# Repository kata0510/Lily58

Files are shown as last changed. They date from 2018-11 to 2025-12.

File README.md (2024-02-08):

# Lily58
Lily58 is 6*4+4keys column-staggered split keyboard.
Lily58Lite-Pic

## [Document Site Here](https://kata0510.github.io/Lily58-Document/)

# Type

- Lily58 Pro
  - [PCB Data](https://github.com/kata0510/Lily58/tree/master/Pro/PCB)
  - [BuildGuide JP](https://kata0510.github.io/Lily58-Document/Lily58_Pro_BG/)
  - [BuildGuide EN](https://github.com/kata0510/Lily58/blob/master/Pro/Doc/buildguide_en.md)
  - [BuildGuide IT](https://github.com/kata0510/Lily58/blob/master/Pro/Doc/buildguide_it.md)
  - [Shop(Yushakobo)](https://yushakobo.jp/shop/lily58-pro/)
- Lily58 Lite Rev2
  - [BuildGuide(YouTube)](https://www.youtube.com/watch?v=t6HLQvqlsVM)
  - [BuildInfo](https://kata0510.github.io/Lily58-Document/Lily58_Lite_Rev2_help.md)
  - [Shop(BOOTH)](https://booth.pm/ja/items/1963895)
  - [Shop(Yushakobo)](https://yushakobo.jp/shop/consign_lily58-lite-rev2/)
- Lily58(Old)
  - [PCB Data](https://github.com/kata0510/Lily58/tree/master/pcb)
  - [BuildGuide](https://kata0510.github.io/Lily58-Document/Lily58_BG/)
- Lily58 Lite Rev1(Old)
  - [PCB Data](https://github.com/kata0510/Lily58/tree/master/pcb)
  - [BuildGuide](https://kata0510.github.io/Lily58-Document/Lily58_Lite_BG/)

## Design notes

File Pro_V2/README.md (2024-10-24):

# Lily58 Pro v2
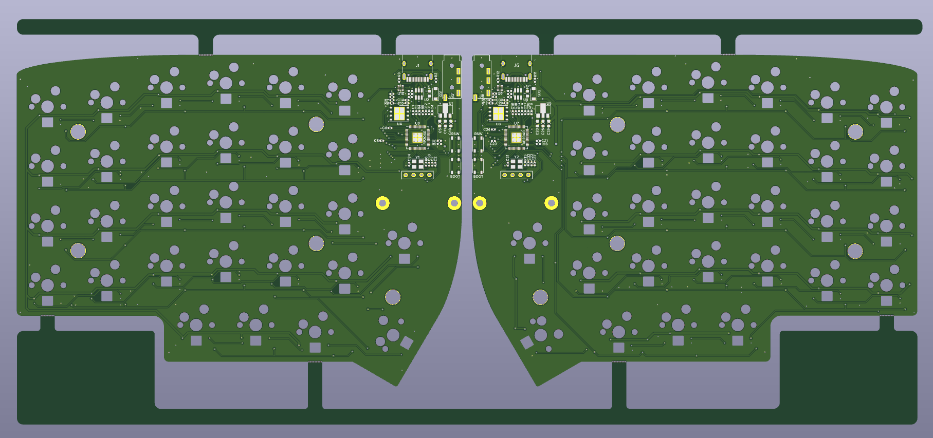
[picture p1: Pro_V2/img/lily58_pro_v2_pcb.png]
Lily58 Pro v2 PCB


### description
- MCU: [RP2040](https://www.raspberrypi.com/documentation/microcontrollers/rp2040.html)
- PCBA Design
- Backlight Support
- Firmware: QMK Firmware

### Assembly Guide
- TBA

### BOM
http://lily58-public.s3-website-ap-northeast-1.amazonaws.com/Lily58_Pro_V2_BOM.html

### Shop
- TBA

### Features
- Choc V2 Switch Support

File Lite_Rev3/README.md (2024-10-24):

# Lily58 Lite Rev3
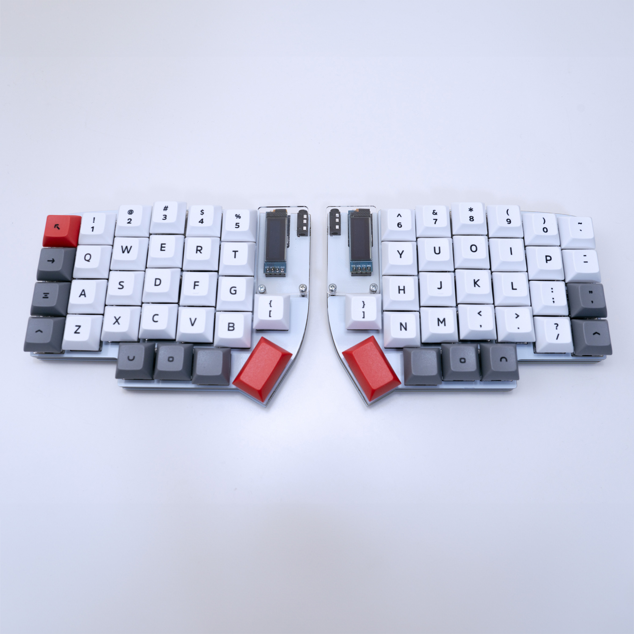
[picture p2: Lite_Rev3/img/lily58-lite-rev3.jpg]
Lily58 Lite Rev3

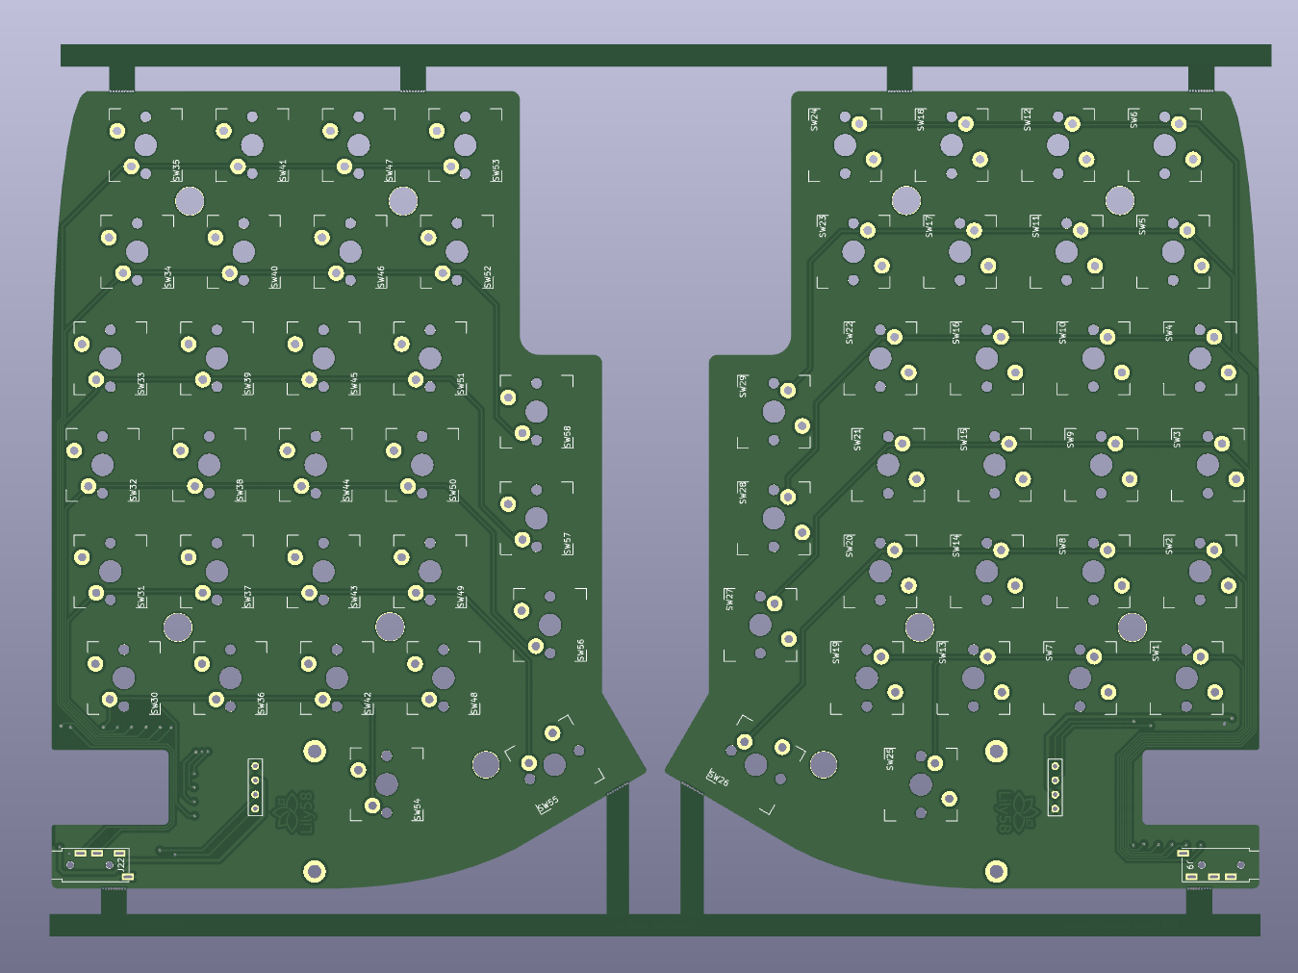
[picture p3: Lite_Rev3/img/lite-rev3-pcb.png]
Lily58 Lite Rev3 PCB

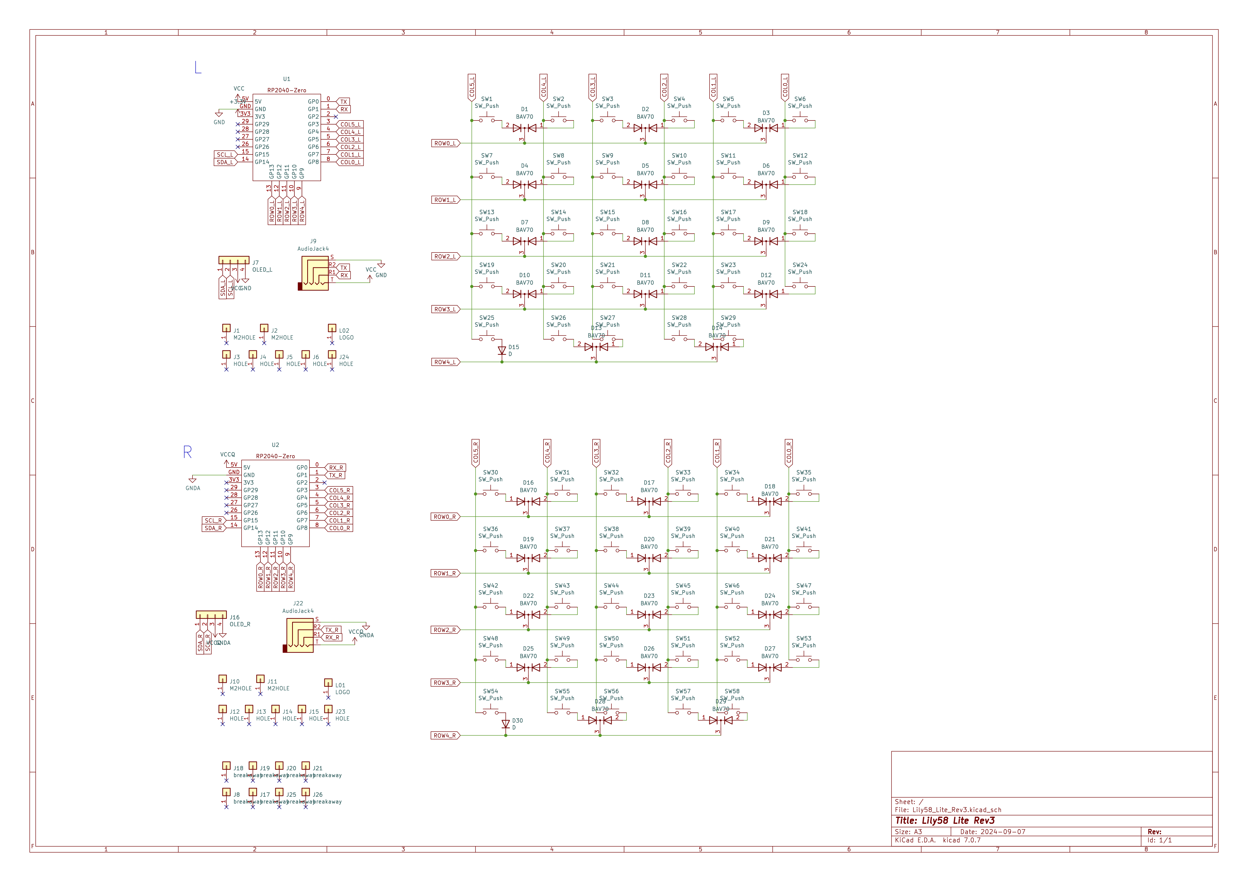
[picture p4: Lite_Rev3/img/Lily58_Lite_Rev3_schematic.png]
Lily58 Lite Rev3 Schematic


### description
- Controller: RP2040-Zero
- Firmware: QMK Firmware

### Assembly Guide
- https://docs.liliums.net/lily58-lite-rev3/about/ (RP2040 installed kit Version)

### Shop
- https://shop.liliums.net/products/lily58-lite-rev3
- https://shop.yushakobo.jp/products/9651

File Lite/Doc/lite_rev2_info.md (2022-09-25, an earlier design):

## 新しいビルドガイドページを参照ください
[https://kata0510.github.io/Lily58-Document/Lily58_Lite_Rev2/](https://kata0510.github.io/Lily58-Document/Lily58_Lite_Rev2/)

## キット組み立てに関する詳細は以下のYouTube動画を参照下さい  
(https://www.youtube.com/watch?v=t6HLQvqlsVM)  

## 組み立てに必要な工具/部品一覧
## 必要な道具
||道具名|備考|
|:---:|---|---|
|1|はんだごて|FX-600等の温調機能があるタイプを推奨|
|2|はんだ||
|3|精密プラスドライバー||
|4|マスキングテープ|はんだ付けする前にパーツを固定するために必要です|
  
## 必要な部品
||パーツ|数量|購入先|
|:---:|---|---|---|
|1|Pro Micro(コンスルー付き)|2|[遊舎工房](https://yushakobo.jp/shop/promicro-spring-pinheader/)|
|2|キースイッチ(MX互換スイッチ※1)|58|[遊舎工房](https://yushakobo.jp/product-category/switches/)など|
|3|キーキャップ|58|[遊舎工房](https://yushakobo.jp/product-category/keycaps/),[TALP KEYBOARD](https://talpkeyboard.stores.jp/)など|
|4|MicroUSB|1|データ通信に対応している物を使用してください|
|5|TRRSケーブル|1|[遊舎工房](https://yushakobo.jp/shop/trrs_cable/)など|
|6|OLEDモジュール(オプション)※2|2|[遊舎工房](https://yushakobo.jp/shop/oled/)|

迷ったときのおすすめ  
キースイッチ:Gateron Silent Red  
https://yushakobo.jp/shop/a02gs/  
  
キーキャップ:MDA BigBang 
https://yushakobo.jp/shop/mda-big-bang-2-0/

※1 CherryMX互換スイッチのみの対応です。ロープロファイルスイッチは使用できません。  
  
※2 OLEDを使用しない場合は以下の手順を行ってください。
  
## OLEDを取り付けない場合
OLEDを取り付けない場合はファームウェアのOLED機能をOFFにする必要があります。  
以下のOLED機能をオフにしたファームウェアをダウンロードしていただき、QMKToolboxで書き込んでいただく、   
もしくはご自身で環境を作っていただきファームウェアをコンパイルして頂く必要がございます。  
‘qmk_firmware/keyboards/lily58/rules.mk‘と  
‘qmk_firmware/keyboards/lily58/keymaps/[キーマップ]/rules.mk‘の‘OLED_DRIVER_ENABLE = yes‘をnoにしてコンパイルし、書き込んでください。

OLEDオフにしたデフォルトキーマップhexファイル
[ダウンロード(lily58_rev1_default.hex)](https://drive.google.com/uc?export=download&id=1yPxZlVRVBfqq0-pEKkJZc93vqW6Jdboj)

## 困ったときは
### 同梱品の部品が足りない
A. 以下のお問合せ先よりご連絡ください。不足分をお送りさせていただきます。  
Twitter:@F_YUUCHI mail:yuchi.kbd@gmail.com 

### Q.1列(複数列)又は1行(複数行)キースイッチが反応しない
A.ProMicroのはんだ付け、取り付けしっかりとできてない場合があります。  
再度確認し、必要に応じて再度はんだ付け、取り付けを行ってください。  

### Q.キースイッチが単体で反応しない
A.キースイッチのはんだづけのはんだ付けに問題がある可能性があります。  
はんだ付けでも解決しない場合、キースイッチが故障している可能性があるため交換が必要です。  

### キーの入力が1つ目で止まる、連続でキーの入力ができない
OLEDを取り付けてない場合ファームウェアでオフにする必要があります。
上記の「OLEDを取り付けてない場合」の手順を行ってください。

**解決しない場合はお気軽にDiscordサーバー([Self-Made Keyboards in Japan](https://discordapp.com/invite/NM7XtDW))の「#clinic-readme」チャンネルを見ていただき相談いただくか、Twitter:@F_YUUCHIにメッセージをお送りください**

## カスタマイズ情報
### Type-C化する
Elite-C LPを購入しProMicroと交換することで接続コネクタをType-C化することができます。  
動作保証いたしかねます。購入される際は事前に調べてからご購入ください。  
https://yushakobo.jp/shop/elite-c-lp/  

### Bluetooth化する
BLE Micro Proを購入しProMicroと交換することでBluetooth化することができます。  
動作保証いたしかねます。導入難易度が高いため購入される際は事前に調べてからご購入ください。  
[https://yushakobo.jp/shop/ble-micro-pro/](https://yushakobo.jp/shop/ble-micro-pro/)

### ケーブルを自作する
MicroUSBケーブルやTRRSケーブルを自作するキットでオリジナルのケーブルを自作することができます  
[https://yushakobo.jp/shop/self-made-cable/](https://yushakobo.jp/shop/self-made-cable/)

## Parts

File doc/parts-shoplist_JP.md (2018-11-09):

| パーツ名 | 販売店舗 |　備考  |
|---|---|---|
|Lily56 ケース|[遊舎工房レーザーカットサービス](https://yushakobo.jp/lasercut/)|Lily58/case/yushakobo-A4.aiデータをA4サイズで発注|
|ProMicro|[遊舎工房](https://yushakobo.jp/shop/promicro-spring-pinheader/)<br> [TALP KEYBOARD](https://talpkeyboard.stores.jp/items/5b24504ba6e6ee7ec60063e3)||
|キースイッチ|[遊舎工房](https://yushakobo.jp/product-category/switches/)<br>[TALP KEYBOARD](https://talpkeyboard.stores.jp/?category_id=59cf8860ed05e668db003f5d)||
|キーキャップ|[遊舎工房](https://yushakobo.jp/product-category/switches/)<br>[TALP KEYBOARD](https://talpkeyboard.stores.jp/?category_id=59be183f428f2d49120007b1)|CherryMX系はTALP KEYBOARD、Kailhロープロ系は遊舎工房での取り扱い|
|ダイオード 1N4148|[秋月電子](http://akizukidenshi.com/catalog/g/gI-00941/)<br>[TALP KEYBOARD](https://talpkeyboard.stores.jp/items/59eadbffc8f22c15de001638)||
|タクトスイッチ|[秋月電子](http://akizukidenshi.com/catalog/g/gP-08074/)|すべて白色のスイッチは国内取扱いなし|
|TRRSジャック|[秋月電子](http://akizukidenshi.com/catalog/g/gC-06070/)||
|M2 スペーサー 6mm,10mm|[ヒロスギネット(6mm)](http://www.hirosugi-net.co.jp/shop/g/g63/)<br>[ヒロスギネット(10mm)](http://www.hirosugi-net.co.jp/shop/g/g71/)||

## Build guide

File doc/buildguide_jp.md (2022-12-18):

# Lily58 ビルドガイド 

## 新しいビルドガイドページを参照ください
[https://kata0510.github.io/Lily58-Document/Lily58_BG/](https://kata0510.github.io/Lily58-Document/Lily58_BG/)

## 必要部品

| パーツ名 |  個数  |  備考  |
|---|---|---|
|Lily58 PCB | 2枚 ||
|Lily58 ケース|1セット||
|ProMicro|2個|はんだ付けの回数が減り、破損しやすいコネクタのため交換が可能になるため別売の[コンスルー](https://yushakobo.jp/shop/a01mc-00/)の使用を推奨|
|キースイッチ(CherryMX,PG1350)|58pcs ※|ALPS軸非対応|
|キーキャップ|1U 56個 1.5U 2個※|1.5Uの部分は1Uでも可|
|ダイオード 1N4148|58本(個)||
|タクトスイッチ|2個||
|TRRSジャック|2個||
|M2 スペーサー 6mm,10mm|10個,4個||
|M2 ネジ 5mm|28個||
|TRS(TRRS)ケーブル|1本|AUXケーブルと言われるオーディオ用のケーブルです|
|MicroUSBケーブル|1本|Pro Micro側のコネクタの耐久性が低いためマグネット式を推奨|

※キットには付属していないため用意が必要です。

## ダイオードを取り付ける
**ロープロファイルスイッチを使用する場合スイッチを取り付けるアクリルプレートとPCBの間の高さを稼げないため別売の[表面実装ダイオード(1N4148W)](http://akizukidenshi.com/catalog/g/gI-07084/)を使用することを推奨します。
付属の足付きダイオードを使用する場合ははんだ付けした面の飛び出しを最小限にする必要があります。(足をカットしてからはんだ付けを行う)**

このPCBはリバーシブルなので**片面づつに**部品を実装していきます。ダイオードを実装する面(オレンジの部品が見える方)が裏面の扱いになります。

横から見るとこのような図になります
PCB2

ダイオードの足を曲げます。
ケース3枚を重ねた状態のものに押し当てると簡単にダイオードの足を曲げることができます。  

 
 PCBの裏側(スイッチやProMicroを取り付けるのと反対側)に折り曲げたダイオードを差し込みます。  
ダイオードには向きがあります。PCBの表記を確認して正しい方向に差し込んで下さい。  
以下の画像のようにダイオードの黒い線が常に基板の表示の三角形の横棒のある方向に向いた状態ではんだ付けをしてください。向きが正しくないとキーが反応しません。
46900579-542c0500-cedf-11e8-87a7-07f710f7e78e
diode  
  
裏側からはんだ付けを行いますが落ちてしまうため、マスキングテープなどで止めます。止める際にダイオードが浮かないようにテープの上から力を加えて抑えながら仮固定します。

はんだ付けを行います。
unadjustednonraw_thumb_2d42

はんだ付けが終わったらダイオードの足をニッパー等でカットします。カットするときに足が飛びやすいため、手で足をつまみながらカットしましょう。
カットが終わったら10mm(長いスペーサー)を取り付けします。
unadjustednonraw_thumb_2d48

## TRRSジャック/リセットスイッチをはんだ付けする
表面の左上にTRRSジャックを取り付けします。どちらも裏返してはんだ付けする際に落ちたりずれやすいのでマスキングテープなどで仮固定します。
unadjustednonraw_thumb_2d4a  
裏側からはんだ付けをします。
unadjustednonraw_thumb_2d4b

## OLED用を使用する場合(オプション)
OLEDを使用する場合は表面のProMicro近くの4つのパッドをジャンパさせてください。   
unadjustednonraw_thumb_2d41

## Pro Microをはんだ付けする
   
#### コンスルーを使用する場合
[コンスルー](https://yushakobo.jp/shop/a01mc-00/)を使用する場合は以下のような取り付け方法を行ってください。
Helixの[ビルドガイド](https://github.com/MakotoKurauchi/helix/blob/master/Doc/buildguide_jp.md#pro-micro)のProMicroの章を参考にはんだ付けを行います。
ProMicro側のみはんだ付けを行い、PCB側ははんだ付けしません。
はんだ付けが終わった後は浮きが無いようにしっかりと差し込みます。

### 付属のピンを使用する場合
Pro Microを袋から取り出し、足が長い方を下にして以下の画像の赤線の内側の**PCBの線で囲まれている列を確認して**PCBに差し込みます。左右で差し込む場所が異なるため注意してください。 

ProMicro_PCB

Pro Microをその上から部品が乗っている面を下向きにして取り付けします。
ProMicro側をはんだ付けをします。
46900581-54c49b80-cedf-11e8-88e1-25a1a2fb378d
46900582-54c49b80-cedf-11e8-9107-83038838a7da

ProMicro側をはんだ付け後マスキングテープ等で固定し基板の裏側からはんだ付けを行います。  
はんだ付け後ニッパーなどで余っているピンをカットします  

## キースイッチを取り付ける
トッププレートにスペーサーとキースイッチを4箇所はめ込み、ピンが曲がらないように注意しながらPCBに取り付けし、浮きや傾きが無いことを確認して4つのスイッチをはんだ付けします。
unadjustednonraw_thumb_2d3e
4dabqoswsoi9o8wor3cdfg_thumb_2d49

トッププレートに残りのスイッチを取り付けをします。   
正常に取り付けできている場合PCBからピンの足が少し出てきますが曲がっている場合やしっかりとはまっていない場合は下側の画像のように足が出てきません。足が曲がっている場合やプレートにしっかりはまっていないので1度取り外すなどして確認して下さい。   
すべてのスイッチを取り付けをしてはんだ付けをします。
48868154-037fc400-ee1c-11e8-9d45-b888f744387a
switch

## ProMicroカバーを取り付け
Pro Micro上部用のアクリルを取り付けます。  
幅が広い方を外側にして取り付けます。低頭ネジで上部をネジ止めします。
promicro_cover
unadjustednonraw_thumb_2d47
## キーマップの書き込み
キーマップを書き込むために準備が必要です。導入されていることを前提に記述しております。[qmk公式のページなどを参考に導入して下さい。](https://docs.qmk.fm/#/getting_started_build_tools)  
  
QMK Toolboxを使用すれば環境構築の必要が無く、GUIで書き込みが行うことができます。(キーマップの変更はできません)
[qmk/qmk_toolbox](https://github.com/qmk/qmk_toolbox/releases)

Lily58のデフォルトキーマップを書き込むにはqmk_firmwareのフォルダ階層で以下を実行します

    make lily58:default:avrdude  

**Detecting USB port, reset your controller now...** と表示されたらキーボード上のリセットボタンを押すと書き込みが始まります。  
上記の要領でもう片方のキーボードにも同じように書き込みを行って下さい。 

Defaultキーマップは以下のようになっています。
lily58_default

## 動作確認
左右をTRRSケーブル(TRSケーブル)で接続し左側のProMicro(デフォルトキーマップの場合)にMicroUSBケーブルを接続しキーが反応するかを確認して下さい。  
裏面にゴム足を4箇所取り付けて完成です。お疲れ様でした。
vu6sptlhszykivrvgkltyw_thumb_2d44

47264498-53384a80-d553-11e8-907a-a03c6f2c5893

## 困ったときは
### Q.1列(複数列)又は1行(複数行)キースイッチが反応しない
A.ProMicroのはんだ付け、取り付けしっかりとできてない場合があります。再度確認し、必要に応じて再度はんだ付け、取り付けを行ってください。

### Q.キースイッチが単体で反応しない
A.キースイッチのはんだづけ又はダイオードのはんだ付けに問題がある可能性があります。

キースイッチの場合
問題のあるキースイッチのはんだ付けを確認してください。はんだが足りてない場合は再度はんだ付けを行ってください。
  
ダイオードのはんだ付けの場合
ダイオードの向きを確認してください。間違っていた場合は外してはんだ付けし直してください。
はんだ付けが足りない場合は再度はんだ付けを行ってください。

**困った場合などはお気軽にDiscordサーバー([Self-Made Keyboards in Japan](https://discordapp.com/invite/NM7XtDW))の「#Lily58」チャンネルもしくはTwitter:@F_YUUCHIにメッセージをお送りください**

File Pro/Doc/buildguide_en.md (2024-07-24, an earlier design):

# Lily58 Pro Build Guide

## Required parts

Part name | Quantity | Remarks | Photo |
| ------- | -------- | ------- | ----- |
| Lily 58 PCB | 2 pieces ||
| Lily 58 case | 1 set (4 pieces) | 2 solid panels, 2 with holes for switches |
| [ProMicro](https://yushakobo.jp/shop/promicro-spring-pinheader/) | 2 pieces | Optionally, use a [spring pin header (con-through)](https://yushakobo.jp/shop/a01mc-00/) to reduce soldering and avoid damage to the fragile ProMicro board. (The recommended con-through part is included in the kit sold at YushaKobo.) ||
| Key switch (Cherry MX, Kailh choc) | 58 pieces | MX switch and choc switches use separate connectors ||
| [Switch socket](https://yushakobo.jp/shop/) | 58 pieces | Necessary for key switch installation ||
| Diodes 1N4148W | 58 pieces |||
| Key caps | 58 pieces | 1.5U caps, can also be 1U ||
| OLED module | 2 pieces |||
| Tact switch | 2 pieces | Tactile reset switch ||
| TRRS jack | 2 pieces ||
| M2 spacer | 10 pieces, 4 pieces | Choc: 4mm, MX: 7mm ||
| M2 screw | 28 pieces |||
| TRRS cable | 1 cable | Cable for 3.5 mmaudio, also called AUX cable (4-pole cable recommended) ||
| Micro USB Cable | 1 pcs | Magnetic connector recommended due to the low durability of the ProMicro socket ||

## Introduction
The Pro version has color variations, and the photos in this build guide are are of the black version, but the white verison is functionally identical. Depending on the color and release date, some parts may differ, but there is no difference in operation.
  
**Note that the case of the black version has a scratch-resistant paint (solder resist) that can arrive with scratches from shipping and transportation. This is the nature of the product.** 

**In addition, please be careful, as the case will be scratched if it hits or rubs a hard thing after assembly.**

This substrate (PCB) is reversible. We will mount parts **on each side.**

Mark the surface with masking tape to make it easy to keep track of the back and front of each board.
51965707-c6841d80-24ad-11e9-8e00-b7113b20fb67
unadjustednonraw_thumb_2ccb

## Attach the diodes
The diodes are supplied in a plastic tape reel. It's easy for the components to fly out when peeling back the tape, so open it slowly and carefully. (It's easier to work the diodes if you cautiously open the container onto a small plate.)


The diodes are mounted on the **back side** of the board.

Solder with the diode wire always pointing in the direction of the arrow symbol drawn on the board (shown in the following figure). If the orientation is incorrect, the key will not respond.


Apply preliminary solder (melt a small amount on the substrate) on one pad of the PCB diode.


Then use tweezers to solder one side of the diode, using the pre-soldering to secure the diode.

Then solder the remaining side.
  
When all diodes have been soldered, check for missing spots.


You can use a multimeter on the front side of the board to ensure that the solder connections are good and that the orientation of the diodes is correct.

## Solder the sockets
The sockets are mounted on the **back side**, the same side as the diodes.

Much like the approach used for the diodes above, begin by pre-soldering one side of the socket pad, place the component, and hold it in place with tweezers. (The sockets can also be held in place by hand, but please take extra care not to burn yourself.)
The image shows a soldered MX socket; please install Choc socket on the lower side.
socket

For parts that require force, firmly solder both pads and check the final result for any looseness/wiggling.


## Soldering the TRRS jack and reset switch
The TRRS jack and the reset switch are mounted on the **front side** (the one with the sticker on the mark).
Attach the parts and fix them temporarily with masking tape. Turn over the board and solder the pins, making sure that the TRRS jack and reset switch are in firm contact with the board.



## Attach the OLED display
On the **front side** of the board, apply enough solder to bridge the four jumper terminals in the ProMicro section.
Attach the connector for the OLED, much like the TRRS jack above. Be careful to avoid adding a lot of solder, as it is easy for solder to flow into the connector.
unadjustednonraw_thumb_2db2

Insert the OLED pin into the socket, attach the OLED module to it, and solder the four pins.

## Install Pro Micro
The pin header enclosed in the bag of ProMicro is not used. For kits purchased at YushaKobo, a spring pin header is included, so use that.

When attaching with a spring pin header (con-through), solder it according to the method described in the Helix build guide and then attach it to the Lily 58 PCB. [Helix build guide](https://github.com/MakotoKurauchi/helix/blob/master/Doc/buildguide_en.md#pro-micro)

Note the **outlined sets of holes in PCB,** and insert the ProMicro into the outlined holes. Please be careful, as the **connections are different for the right and left boards.**

ProMicro_PCB

## Attach the spacer
Attach four 10mm round spacers to the holes near ProMicro.
It's easy to insert a screw from the back of the board and attach the spacer from the top.


Peel off the masking tape used to identify the front and back of the board.

## Attach the key switch
Attach the top plate spacers for alignment. (MX: 7mm Choc: 4mm)



Attach four key switches to the top plate. (In the case of Choc switches, starting with two switches in the plate may be easier.)

  
Insert the switch into the board for alignment, and line up the components.


After confirming that there are no bends in the switch pins, you can attach it firmly by starting from the middle row and working outward.
Be careful: KailhBOX switches and Choc switches require some power for installation.
After mounting the plate, push the switches again to make sure that installation is complete.


## ProMicro protective acrylic installation
Peel off the protective plastic layer covering the acrylic, and attach the acrylic to the board.
**Mount with the wider side (labeled "幅が広い" here) outwards.** 

Attach with screws.



## Write key map
The board requires a keymap in order to function. This section assumes that you're familiar with keymaps and the use of the QMK tool. If not, please refer to [the QMK "Getting Started" guide](https://docs.qmk.fm/#/getting_started_build_tools) (Windows: MSYS2; Mac, Linux: avrdude)

The [QMK Toolbox](https://github.com/qmk/qmk_toolbox/releases) can be used to write non-customized keymaps via a GUI, avoiding the need to configure a local QMK environment. (For custom keymaps, it's recommended to build the full environment described above).

Execute the following in the `qmk_firmware` directory to write the default Lily58 keymap

    sudo make lily58:default:avrdude

When **`Detecting USB port, reset your controller now ...`** is displayed, press the reset button on the keyboard to start writing.
Each half of the keyboard must be programmed separately using this approach.

## Default keymap
The default keymap is laid out on the assumption that it will be used in the MacOS/US keyboard environment. Feel free to get creative and experiment with keymaps that match your preferences; consider changing to the JIS layout or adding a key to switch between English and Kana, for example.

The best of my own keyboard:
lily58_default

## Operation check
Connect the left and right sides with a TRRS cable, connect the MicroUSB cable to ProMicro on the left side (in the case of the default key map), and check if the key responds.
The build is completed by attaching the four rubber feet to the back of each board. Thank you for your hard work.

unadjustednonraw_thumb_2ddc

## When in trouble
### Q. One or more rows/columns of key switches do not respond
A. The ProMicro board may not be soldered and attached firmly. Check again, and re-solder and reinstall if necessary.

### Q. A single key switch doesn't respond 
A. There may be a problem with the key switch's insertion, socket or diode soldering.

In the case of bad key switch insertion:
After removing the key switch, make sure that the pins aren't bent, and then push it in again and install it.

In the case of badly attached socket:
Re-solder the problem socket, or reflow and add solder if the joint is weak.
  
In the case of badly attached diode:
Check the direction of the diode in question. If it is wrong, remove it and re-solder it. Additionally, if there isn't enough solder, please re-solder.

### Q. A symbol different from the symbol input by "@" or "[" etc. is input (on Windows, etc.)
Since recognition of keyboard is recognized as JIS keyboard on OS, another symbol will be input when inputting with Lily 58 (treated as US keyboard).
Please set Lily 58 as a US keyboard in the OS keyboard settings. After switching, switching to Japanese input becomes the switching key for the US keyboard, and it differs from the JIS keyboard, so please be careful (it can be customized with the key map etc.).

**If you have any problems, please feel free to send a message to the "#Lily58" channel on Discord ("Self-Made Keyboards in Japan" (https://discordapp.com/invite/NM7XtDW)) or Twitter: @F_YUUCHI**

## Change the key map
This self-made keyboard use the QMK firmware, described above. The QMK firmware is highly customizable, and you can unlock a lot functionality simply by editing the key map.
### Edit keymap.c and customize
When customizing a keymap, start by making a copy of the `qmk_firmware/keyboards/lily58/keymaps/default` folder and modifying that directory's internal `keymap.c` file.
Please refer to the [official QMK documentation](https://docs.qmk.fm/#/keycodes) for the key codes and programming specifics.

After changing the key map,

    sudo make lily58:(any folder name):avrdude

If you get an error, please double-check the board, connection and command.
  
### How to customize using QMK Configurator (deprecated)
If you use [QMK Configurator](https://config.qmk.fm/#/lily58/rev1/LAYOUT), you can create an original keymap on the browser without editing the `keymap.c` file.
Load the downloaded JSON file into the QMK Toolbox and write it to the boards.

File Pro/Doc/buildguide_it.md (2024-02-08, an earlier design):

# Lily58 Pro Guida al montaggio [WIP]

## Parti necessarie

| Nome parte | Quantità | Note | Foto |
| --- | --- | --- | ---- |
| PCB Lily 58 PCB | 2 pezzi | |
| Rivestimento Lily 58 | 1 confezione (4 pezzi) | 2 pannelli pieni, 2 con fori per interruttori |
| [ProMicro](https://yushakobo.jp/shop/promicro-spring-pinheader/) | 2 pezzi | Opzionalmente, usare una [testata con perno a molla (passante)](https://yushakobo.jp/shop/a01mc-00/) per ridurre la saldatura ed evitare danni alla fragile scheda del ProMicro. (Il componente passante consigliato è incluso nel kit venduto da YushaKobo.) | |
| Interruttori tasti (Cherry MX, Kailh Choc) | 58 pezzi | Interrottori MX e Choc usano connettori diversi | |
| [Connettore interruttori](https://yushakobo.jp/shop/) | 58 pezzi | Necessari per l'installazione degli interruttori | |
| Diodi 1N4148W | 58 pezzi | | |
| Copritasti | 58 pezzi | Copritasti 1.5u, possono essere anche 1u | |
| Moldulo OLED | 2 pezzi | | |
| Interruttore tattile | 2 pezzi | Interruttore tattile per il reset | |
| Presa TRRS | 2 pezzi | | |
| Distanziatore M2 | 10  pezzi, 4 pezzi | Choc: 4mm, MX: 7mm | |
| Vite M2 | 28 pezzi | | |
| Cavo TRRS | 1 cavo | Cavo audio da 3.5mm, chiamato anche  cavo AUX (raccomandato il 4-poli) | |
| Cavo Micro USB | 1 pezzo | Connettore magnetico raccomandanto a causa dell fragilità della presa ProMicro | |

## Introduzione
La versione Pro ha varianti di colore e le foto in questa guida al
montaggio sono della versione nera, ma la versione bianca è
funzionalmente identica.

In base al colore e alla data di rilascio, alcune parti potrebbero
essere differenti, ma non c'è nessuna differenza di funzionamento.

**Notare che il rivestimento della versione nera ha una verniciatura
antigraffio (resistente alla saldatura) che può arrivare con graffi
derivanti dalla spedizione e trasporto.
Questa è una cosa tipica del prodotto.**

**In aggiunta, fare attenzione che il rivestimento può graffiarsi se urta
o sfrega una cosa dura, dopo il montaggio.**

La scheda (PCB) è reversibile.
Montiamo le parti **su entrambi i lati**.

Segnare la superficie con del nastro per indicare chiaramente il fronte
e il retro di ciascuna scheda.
51965707-c6841d80-24ad-11e9-8e00-b7113b20fb67
unadjustednonraw_thumb_2ccb

## Attaccare i diodi
I diodi sono forniti in un contenitore a nastro di plastica.
E' facile far cadere i componenti quando si rimuove il nastro, quindi
aprire con calma e con cura.
(E' più facile gestire i diodi se si apre il contenitore con cura sopra
un piccolo piatto.)

I diodi vanno montati sul **retro** della scheda.

Saldare colla cablatura del diodo che punta sempre nella direzione della
freccia disegnata sulla scheda (mostrata nella figura successiva).
Se l'orientamento non è corretto, il tasto non risponde.


Applicare una saldatura preliminare (sciogliere una piccola quantità sul
substrato) di un piedino del diodo sulla scheda.


Quindi usare delle pinzette per saldare un lato del diodo, usando la
pre-saldatura per assicurare il diodo.

Quindi saldare il lato rimanente.

Quando tutti i diodi sono stati saldati, controllare eventuali punti
mancanti.


Si può usare un multimetro sul fronte della scheda per assicurarsi che
le connessioni saldate siano buone e che l'orientamento dei diodi sia
corretto.

## Saldare i connettori
I connettori sono montati sul **retro**, sullo stesso lato dei diodi.

Come nell'approccio usato sopra per i diodi, si può iniziare con una
pre-saldatura di un lato del connettore, piazzare quindi il componente e
tenerlo in posizione con delle pinzette.
(I connettori possono essere tenuti in posizione anche a mano, ma fate
attenzione a non bruciarvi.)
L'immagine mostra un connettore MX saldato; si prega di installare i
connettori Choc sul lato inferiore.
socket

Per parti che richiedono forza, saldare fermamente entrambe le
connessioni e verificare che il risultato finale non sia molle o non
fisso.


## Saldare il connettore TRRS e il tasto reset
Il connnettore TRRS e il tasto reset vanno montati sul **fronte**
(quello marcato col nastro adesivo).
Attaccare le parti e fissarle temporaneamente col nastro.
Gira la scheda e salda i piedini, assicurandoti che il connettore TRRS e
il tasto reset siano attaccati fermamente alla scheda.



## Attacca lo schermo OLED
Sul **fronte** della scheda, utilizza sufficiente saldatura per
collegare i quattro terminali nella sezione del ProMicro.
Attacca il connettore per l'OLED come il connettore TRRS sopra.
Attenzione a non usare troppa saldatura, poiché può finire nel
connettore.
unadjustednonraw_thumb_2db2

Inserisci i piedini OLED nel connettore, collega il modulo OLED e salda
i quattro piedini.

## Installa il Pro Micro
La spina inclusa nel sacchetto ProMicro non deve essere usata.
Per i kit acquistato da Yyushakobo, è inclusa una spina con perno a
molla, quindi usa quella.


Quando si attacca la spina con perno a molla (passante), saldarla
secondo il metodo descritto nella guida al montaggio della Helix e
quindi attaccarla alla scheda Lily 58.
[Guida al montaggio Helix](https://github.com/MakotoKurauchi/helix/blob/master/Doc/buildguide_jp.md#pro-micro)

Notare i **fori evidenziati sulla scheda**, e inserire il ProMicro in
quei fori.
Attenzione, i **collegamenti sono diversi tra destra e sinistra**.

ProMicro_PCB

## Attacca il distanziatore
Attacca i quattro distanziatori circolarei da 10mm vicino al ProMicro.
E' facile inserire una vite dal retro della scheda e attaccare il
distanziatore dall'alto.


Rimuovere il nastro che identifica fronte e retro della scheda.

## Attaccare gli interruttori
Attaccare i distanziatoro sul rivestimento superiore, per allineamento.
(MX: 7mm Choc: 4mm)



Attaccare quattro interruttori sul rivestimento superiore.
(In caso di interruttori Choc, iniziare con due interruttori può essere
più facile.)


Inserire l'interruttore sulla scheda per allineamento, e allinearlo coi
componenti


Dopo aver verificato che non ci sono pieghe nei piedini
dell'interruttore, puoi attaccarlo rigidamente iniziando dalla fila
centrale e andando verso l'esterno.
Attenzione: gli interruttori Kailh Box e Choc richiedono un po' di forza
per l'installazione.

Dopo che il montaggio è completo, spingere ancora gli interruttori per
verificare l'installazione.


## Installazione della protezione acrilica ProMicro
Rimuovere la plastica protettica che copre la protezione acrilica e
attaccarla sulla scheda,
**Montare il lato più largo (indicato con "幅が広い" in figura) all'esterno.**

Avvitare.



## Scrivere la mappa caratteri
La scheda richiede una mappa caratteri per funzionare.
Questo paragrafo suppone che tu abbia familiarità colle mappe carattere
e l'uso dello strumento QMK.
Altrimenti, fai riferimento alla guida
[Getting Started](https://docs.qmk.fm/#/getting_started_build_tools) di
QMK.
(Windows: MSYS2; Mac, Linux: avrdude)

Si può usare lo
[strumento QMK](https://github.com/qmk/qmk_toolbox/releases) per
scrivere mappe carattere non personalizzate tramite GUI, evitando la
necessità di configurare un ambiente QMK locale.
(Per le mappe carattere personalizzate, si consiglia la preparazione
dell'intero ambiente come descritto sopra.)

Esegui il seguente comando nella cartella `qmk_firmware` per scrivere la
mappa caratteri predefinita di Lily58:
```shell
sudo make lily58:default:avrdude
```
Quando si legge
```text
Detecting USB port, reset your controller now ...
```
si può premere il tasto reset sulla tastiera per iniziare la
memorizzazione.
Ciascuna delle due metà della tastiera deve essere programmata
separatamente usando questo approccio.

## Mappa caratteri predefinita
La mappa caratteri predefinita è stata creata assumendo che venga usata
in un ambiente MacOS/US.
Sentiti libero di essere creativo e di sperimentare con mappe carattere
che seguano le tue preferenze; considera la possibilità di cambiare al
layout JIS o aggiungere tasti per passare da inglese a kana, per esempio.

Il meglio sulla mia tastiera:
lily58_default

## Controllo operazioni
Collegare i lati destro e sinistro con un cavo TRRS, collegare il cavo
Micro USB al ProMicro di sinistra (in caso di mappa caratteri
predefinita), e controllare che i tasti rispondano.

Il montaggio è completo aggiungendo i quattro piedini di gomma sul retro
di ciascuna scheda.
Grazie per il tuo lavoro.

unadjustednonraw_thumb_2ddc

## In caso di problemi
### Q. Una o più righe/colonne degli interruttori non risponde
A. Il ProMicro potrebbe non essere saldato e collegato correttamente.
Ricontrolla, ri-salda e reinstalla se necessario.

### Q. Un tasto non risponde
A. Potrebbe esserci un problema con l'inserimento di quell'interruttore,
connettore o diodo.

Nel caso di errato inserimento dell'interruttore: dopo aver rimosso
l'interruttore assicurati che i piedini non siano piegati e quindi
rimettilo dentro e installa di nuovo.

Nel caso di errato collegamento del connnettore: ri-salda il connettore
col problema oppure migliora la saldatura se il collegamento è debole.

Nel caso di diodo mal collegato: controlla la direzione del diodo in
questione.
Se è sbagliata, rimuovilo e ri-saldalo.
inoltre, se non c'è abbastanza saldatura, ri-salda.

### Q. Viene fuori un simbolo diverso ("@" o "[", ecc.) da quello digitato (su Windows, ecc.)
Dato che la tastiera viene riconosciuta come JIS dal sistema operativo,
potrebbe comprarire un altro simbolo.
Si prega di impostare la Lily 58 come tastiera US nelle impostazioni del
sistema operativo.
Dopo aver cambiato configurazione, il passaggio all'input giapponese
viene fatto dalla tastiera US e risulta diverso dalla tastiera JIS
quindi si prega di fare attenzione (può essere personalizzato nella
mappa caratteri, ecc.)

**In caso di problemi, manda pure un messaggio sul canale #Lily58 su
Discord ("Self-Made Keyboards in Japan"
(https://discordapp.com/invite/NM7XtDW)) o Twitter: @F_YUUCHI**.

## Cambiare la mappa caratteri
Questa tastiera fatta in casa usa il firmware QMK descritto sopra.
Il firmware QMK è altamente personalizzabile e puoi sbloccare un sacco
di funzionalità semplicemente modificando la mappa.

### Modifica `keymap.c` e personalizza
Quando si personalizza una mappa caratteri, inizia facendo una copia
della cartella `qmk_firmware/keyboards/lily58/keymaps/default` e
modificando il file `keymap.c` dentro quella cartella.
Fai riferimento alla
[documentazione ufficiale QMK](https://docs.qmk.fm/#/keycodes) per i
codici dei tasti e i dettagli della programmazione.

Dopo aver cambiato la mappa caratteri,
```shell
sudo make lily58:(any folder name):avrdude
```
Se ricevi un errore, ricontrolla la scheda, connessione e comando.

### Come personalizzare usando il configuratore QMK (deprecato)
Se usi il [configuratore QMK](https://config.qmk.fm/#/lily58/rev1/LAYOUT),
puoi creare una mappa caratteri originale dal browser, senza modificare
il file `keymap.c`.
Carica il JSON scaricato nel Toolbox QMK e scrivilo sulle schede.

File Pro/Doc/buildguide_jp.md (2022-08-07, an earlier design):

# Lily58 Pro ビルドガイド

## 新しいビルドガイドページを参照ください
https://kata0510.github.io/Lily58-Document/Lily58_Pro_BG/

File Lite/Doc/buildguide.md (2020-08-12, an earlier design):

## 新しいビルドガイドページを参照ください
[https://kata0510.github.io/Lily58-Document/Lily58_Lite_BG.html](https://kata0510.github.io/Lily58-Document/Lily58_Lite_BG.html)

## 内容品の確認
キットの内容品の確認をします。  
IMG_4126のコピー

# 組み立て
## 必要な道具
|道具名||
|---|---|
|はんだごて|はんだ付けをするために必要です。温調機能があるタイプを推奨します(FX-600等)|
|はんだ||
|ニッパー|ダイオードの足をカットするために必要です|

## 基板を確認する
Lily58と書かれている面が表面となります。


## ダイオードを取り付ける
付属している9mm幅のアクリルダイオードベンダーでダイオードの足を折り曲げます。

ない場合はケースを3枚重ねると9mm幅になり、同じようにダイオードの足を折り曲げることができます。

基板を裏側にし、三角形に横棒がある向き(上側)をダイオードの黒い線が来るように差し込みます。向きが正しくないと完成後キーが反応しません。


差し込んだ後、裏側からはんだ付けをします。
裏返す際にダイオードが落ちたりしてしまうため、マスキングテープなどで仮固定します。



はんだ付け後、ダイオードの足をニッパーなどでカットします。


## TRRSジャック/リセットスイッチをはんだ付けする
TRRSジャックとリセットスイッチをはんだ付けします。
基板に差し込んだらマスキングテープで仮固定し、裏側からはんだ付けをします。




## OLEDソケットを取り付けする

OLEDソケットを差し込み、マスキングテープで仮固定します。


はんだの量が多いとソケット内に流れ込んでしまうため、気をつけてください。


## Pro Microをはんだ付けする
Pro MicroのUSBコネクタは破損しやすいため、破損時に交換がしやすいスプリングピンヘッダ(コンスルー)を使用することを推奨しています。
遊舎工房でPro Microを購入している場合付属していますのでそちらを使用します。

スプリングピンヘッダ(コンスルー)には取り付け推奨向きがあります。
Helix[ビルドガイド](https://github.com/MakotoKurauchi/helix/blob/master/Doc/buildguide_jp.md#pro-micro)に記述されているように、コンスルーの小さい窓がある方向をPro Micro側(上側)になるようにします。
2本とも差し込んだ後、Pro Microを部品が下側になるように差し込みます。この時に少し強く押し込み、完全に差し込まれるようにします。




曲がっていたり、浮きが無いことを確認し、Pro Micro側のみをはんだ付けをします。抜き差しを可能にするため **基板側にははんだ付けを行わないでください**

## キースイッチを取り付ける
アクリルケースのトッププレート(スイッチ穴が空いている方)を取り出し、保護シートを剥がします。
トッププレートにスペーサーを取り付けます。  
スペーサー(短)とネジを取り出し、ネジを上側から通してからスペーサーを下側から回し、手で取り付けをします。  
キースイッチを写真の位置に4箇所差し込み、基板と合わせます。この際にズレやピンの曲がりがないよう注意しながらPCBに対して上からまっすぐ下ろして取り付けをし、スイッチが浮きや傾きが無いことを確認して4つのスイッチをはんだ付けします。  
その後、残りのスイッチを差し込んではんだ付けをします。

スペーサー(長)とネジを使い、OLEDプレート用のスペーサーを取り付けます。

ボトムプレートの保護フィルムを剥がし、ネジ止めをします。  
その後、ゴム足を貼り付けます。


## OLEDモジュールを取り付けする
OLEDモジュールを取り出し、ソケットにピンを差し込んでその上からOLEDモジュールを載せ、はんだ付けをします。  
その後OLEDカバーを取り付けます。


### OLEDを取り付けない場合
OLEDを取り付けない場合はファームウェアのOLED機能をOFFにする必要があります。  
以下のOLED機能をオフにしたファームウェアをダウンロードしていただき、QMKToolboxで書き込んでいただく、   
もしくはご自身で環境を作っていただきファームウェアをコンパイルして頂く必要がございます。  
‘qmk_firmware/keyboards/lily58/rules.mk‘と  
‘qmk_firmware/keyboards/lily58/keymaps/[キーマップ]/rules.mk‘の‘OLED_DRIVER_ENABLE = yes‘をnoにしてコンパイルし、書き込んでください。
  
OLEDオフにしたデフォルトキーマップhexファイル
[ダウンロード(lily58_rev1_default.hex)](https://drive.google.com/uc?export=download&id=1yPxZlVRVBfqq0-pEKkJZc93vqW6Jdboj)
  
## キーマップの書き込み
キーマップを書き込むために準備が必要です。導入されていることを前提に記述しております。[qmk公式のページなどを参考に導入して下さい。](https://docs.qmk.fm/#/getting_started_build_tools)  
  
QMK Toolboxを使用すれば環境構築の必要が無く、GUIで書き込みが行うことができます。(キーマップの変更はできません)
[qmk/qmk_toolbox](https://github.com/qmk/qmk_toolbox/releases)

Lily58のデフォルトキーマップを書き込むにはqmk_firmwareのフォルダ階層で以下を実行します

    make lily58:default:avrdude  

**Detecting USB port, reset your controller now...** と表示されたらキーボード上のリセットボタンを押すと書き込みが始まります。  
上記の要領でもう片方のキーボードにも同じように書き込みを行って下さい。 

Defaultキーマップは以下のようになっています。
lily58_default

## 動作確認
左右をTRRSケーブル(TRSケーブル)で接続し左側のProMicro(デフォルトキーマップの場合)にMicroUSBケーブルを接続しキーが反応するかを確認して下さい。  
動作確認をして完了です、組み立てお疲れ様でした。

## 困ったときは
### Q.1列(複数列)又は1行(複数行)キースイッチが反応しない
A.ProMicroのはんだ付け、取り付けしっかりとできてない場合があります。再度確認し、必要に応じて再度はんだ付け、取り付けを行ってください。

### Q.キースイッチが単体で反応しない
A.キースイッチのはんだづけ又はダイオードのはんだ付けに問題がある可能性があります。

キースイッチの場合
問題のあるキースイッチのはんだ付けを確認してください。はんだが足りてない場合は再度はんだ付けを行ってください。
  
ダイオードのはんだ付けの場合
ダイオードの向きを確認してください。間違っていた場合は外してはんだ付けし直してください。
はんだ付けが足りない場合は再度はんだ付けを行ってください。

**困った場合などはお気軽にDiscordサーバー([Self-Made Keyboards in Japan](https://discordapp.com/invite/NM7XtDW))の「#mon-shin」チャンネルもしくはTwitter:@F_YUUCHIにメッセージをお送りください**

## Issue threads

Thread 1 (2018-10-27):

Kailhロープロファイルだとアクリルケース邪魔でキーキャップが設置出来ない

t10471, 2018-10-27:
Kailhロープロファイル対応と書いてあると思うのですが、
遊舎工房さんで買った `Kailhロープロファイルスイッチ` と `Kailhロープロ無刻印(遊刻印)キーキャップ` だとキーの高さに対して上のアクリルケースが邪魔でキーキャップが設置出来ません。
Kailhロープロファイル用のアクリルケースとスペーサーが欲しいです。

t10471, 2018-10-27:
これがはめた画像です。
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

遊舎工房さんで(https://yushakobo.jp/shop/pg1350/)買ったものだと、
アクリルケースの穴よりちょっと大きい気がします...
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

kata0510, 2018-10-27:
写真を見させていただいたところ組み立て方に間違いがあるようです。
ロープロファイルの場合PCBとスイッチをマウントするアクリルの間に隙間が生まれないためダイオードは**裏側に**はんだ付けをする必要があります。
スイッチをアクリルに取り付けるにはコツがありますが斜めの状態でスイッチ側面の爪の部分を押し込むと取り付けられるかと思います。
この場合ですと一旦スイッチのはんだ付けをすべて外し、ダイオードが裏側に来るように左右のPCBを逆にしてからスイッチをアクリルに取り付けてサイドはんだ付けを行う必要があります。

t10471, 2018-10-28:
なるほど、、、もう一セット買おうかと思います。。。

kata0510, 2018-10-28:
半田吸い取り線でスイッチを取り外して正しく組み直せば十分対処できる範囲かと思います。また何か質問などあればTwitterにて対応出来ますのでよろしくお願いします。

Closed 2018-10-28.

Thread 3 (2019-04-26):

Problems with the gerber files (non pro lily58)

caileighf, 2019-04-26:
Hi! I tried to order the PCBs from a fab shop I've used before but it looks like the gerber only has the copper traces. Would you be willing to upload gerbers with all the necessary layers? Or if you could let me know how it's supposed to be done in KiCad if that's were you designed it. I really love the board you've made.
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

kata0510, 2019-05-06:
Please plot the file with the setting suitable for the PCB factory by the procedure of File-> Plot
The uploading Gerber is for elecrow
thanks!
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

caileighf, 2019-05-07:
This is great! Thank you for the instructions.

Closed 2019-05-07.

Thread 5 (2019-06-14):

How to print the plates ?

3r1kd0f, 2019-06-14:
Hello,

First of  all, thank you so much for open sourcing this project.

How should those files be used to produce the plates / case ?

I see that the case or the plates are in .ai format - how can those files be used for CNC machining ? Usually it requires extensions like STEP, IGES, SLDPRT, 3DM, IPT, SAT

Kicad allows to export in STEP format but when exporting, I get error message "Cannot determine the board outline" for file Lily58_Pro_BOTTOM.kicad_pcb.

Thanks !

3r1kd0f, 2019-06-15:
After investigation, it seems ai file is proper for laser cutting. Closing the issue.

Closed 2019-06-15.

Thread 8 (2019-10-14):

Right half not working (Lily58 Pro)

BenRoe, 2019-10-14:
Hello,
i need some help.
I flashed the pro micro's with the default rev1 keymap. `make lily58/rev1:default:avrdude`.

If i test both side separate (via USB), they send keycodes. The right half has the layout from the left half.

If i connect the left half via USB and connect both sides with the trrs cabel (4pole), left works, but right sends no keycode.
Any idea what the problem could be?

Disabled the backlight in the rule.mk, desoldered the bridges for the oled.

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

BenRoe, 2019-10-15:
I also soldered mx and choc sockets. This shouldn't be a problem, right?

BenRoe, 2019-10-15:
Ok i fixed the problem.
Seems that some pins are not connected, because i used the [spring pin header](https://user-images.githubusercontent.com/6285554/57210525-f5171480-7017-11e9-9d92-3a345d53db94.jpg).

Now i use the mill-max pin header and everything works.
Hope this helps, if someone has a similar problem to fix it faster.

ikakus, 2019-12-26:
Hi! I have the same problem.
I have a hoy swap sockets for pro-micros. I've tried 3 different pro-micro combinations still the problem remains.

My guess is, maybe I've damaged this conduction "road". Can you please advise if I can connect the damaged circuit with a wire directly from pro micro pin to TRRS jack? If yes, which one should I connect?

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

Closed 2019-10-15.

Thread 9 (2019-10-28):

Lily58Pro I installed the pro micro in wrong ports, would it stop the keyboard from flashing ?

harshitgoel96, 2019-10-28:
Hi,

I have installed the pro micro on the incorrect pads, and now i can not flash the pro micro,
I am not testing the keyboard right now, but only trying to flash the firmware. I am getting "can not connect to programmer" or "no device found"

harshitgoel96, 2019-11-07:
installing correct side of pcb, makes the pro micro flash properly.

Closed 2019-11-07.

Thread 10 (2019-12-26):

Right half not working (Lily58 Pro)

ikakus, 2019-12-26:
Hi! I have a problem.
I flashed the pro micro's with the default rev1 keymap. make lily58/rev1:default:avrdude.

If I test both side separately (via USB), they send keycodes. The right half has the layout from the left half.

If I connect the left half via USB and connect both sides with the trrs cable (4pole), left works, but right sends no keycode.
Any idea what the problem could be?
I have hot swap sockets for pro-micros. I've tried 3 different pro-micro combinations still the problem remains.

My guess is, maybe I've damaged this conduction "road". Can you please advise if I can connect the damaged circuit with a wire directly from pro micro pin to TRRS jack? If yes, which one should I connect?

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

_Originally posted by @ikakus in https://github.com/kata0510/Lily58/issues/8#issuecomment-569059133_

kata0510, 2019-12-26:
Hi
Using blue ProMicro?
Blue ProMicro recommends using black ProMicro due to left / right communication issues.

ikakus, 2019-12-26:
Yes, blue ones. Oh wow, I thought they are all the same!
Thanks, I will try with black ones!
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

ikakus, 2019-12-26:
I think I've found the problem that you mentioned, but it is about **green** ones.
[green micro vs blue](http://www.40percent.club/2017/09/green-pro-micro.html).
Altho the only black micros that I've found are Elite-C, were you referring to them?

BenRoe, 2019-12-26:
I have the same problem with a Lily58 keyboard from a customer. Tomorrow i replace the pro micro with different pro micro's and elite-c and post the result here.

There is another fix. A different slave detection method ([PR](https://github.com/qmk/qmk_firmware/pull/6424)).

> “A few of us collaborators of the QMK Firmware reviewed and tested the new option, signed off on it, and then it got merged in. So to use the new detection method (which does not rely on the Schottky diode), in config.h of your keymap, add the…” — @keebio https://link.medium.com/kmZ3dambK2

Would be great if the Lily58 uses the new `split_common` framework.

kata0510, 2019-12-27:
The problem that blue ProMicro cannot communicate left and right has been reported in Japan.
https://twitter.com/yohewi/status/1204048124244717568

I can't verify because I don't have Elite-C. sorry.

ikakus, 2019-12-27:
@BenRoe, I'm using regular pro micros (with micro-usb port), do you think this is still related?

BenRoe, 2019-12-27:
Did some test with different pro micro's.
Left one works if on both sides. Also the Elite-C works. Will compare both under a magnifier to find difference.
First obvious difference is the micro usb port.
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

CurryFurious, 2020-01-02:
YMMV, But for me I switched to a from a 4 pole TRRS cable to a 3 pole TRS Cable, and for whatever reason it actually work. If you want to try the lily58 with split common code, check out my personal fork of qmk, it has both the CRKBD and Lily58 working with split common. You might need to add `SPLIT_TRANSPORT = yes` in your keymaps rules.mk for it to work properly, or you can try my keymap (make lily58:curry:flash), however it is meant for the elite-c.

ikakus, 2020-01-04:
@CurryFurious I've tried with 3 pole TRS, still same issue. I'm still waiting for black ProMicro's to arrive, will post an update once I'll try them.

ikakus, 2020-01-15:
So, I've finally got to try **black** pro-micros on both sides, and it has the same issue. Can you please tell me what pins are used for two sides connection I'll try to solder them directly.

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

aWalrus, 2020-01-17:
I had a similar issue! Are you, by any chance, using RGB LED backlight?
6 LEDs per half in my build (with full brighness) was too much and lead to brownouts - with one half not working.
As soon as I disabled them, the issue was gone.

ikakus, 2020-01-17:
@aWalrus Hi! No, I have only both types of sockets, reset switch, trrs and pro-micros soldered.

ikakus, 2020-01-18:
@kata0510 can I use this connection? I want to solder them directly to exclude pcb problem?
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

ikakus, 2020-01-20:
So I was able to fix the issue. It appeared physical damage as I suggested before.
As SOFT_SERIAL_PIN set to PD2 in file serial_config.h. I've just connected them directly with a wire.
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 and it solved the problem.

Then I just soldered PD2 pin to TRRS on the damaged board.
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

No problems so far :)

BiotechPedro, 2021-02-28:
> YMMV, But for me I switched to a from a 4 pole TRRS cable to a 3 pole TRS Cable, and for whatever reason it actually work. If you want to try the lily58 with split common code, check out my personal fork of qmk, it has both the CRKBD and Lily58 working with split common. You might need to add `SPLIT_TRANSPORT = yes` in your keymaps rules.mk for it to work properly, or you can try my keymap (`make lily58:curry:flash`), however it is meant for the elite-c.

@Curry I've tried with your keymap but still I suffer the same problem... using 2 elite-c and trying to flash a lily58 default keymap, the right part doesn't do anything. Sometimes the left hand functions perfectly and others only "z", "x", "b", "v" "[" and " " works. Can you help me please?

fi0, 2021-06-07:
@BiotechPedro which version of elite-c are you using?

hzx, 2023-01-05:
in keymap/config.h you need to define:
#define SPLIT_USB_DETECT
also choose hand for each promicro:
controller have left hand buttons
#define MASTER_LEFT
controller have right hand buttons
#define MASTER_RIGHT

NotNite, 2023-04-17:
Running into this too - I tried with SPLIT_USB_DETECT but nothing.

Closed 2020-01-20.

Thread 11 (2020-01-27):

Lily58 Pro case sizes

IgorLGMS, 2020-01-27:
Hi and thank you for your work and dedication to the keyboard community!

I contacted a laser cutting company to cut a Lily 58 pro case, but they replied that the files I gave them didn't have any sizes on them, what are the correct sizes to cut that plates?

Or what is the correct way to get the plates cut?

kata0510, 2020-01-27:
Hi!
Use this data when cutting acrylic cases
https://github.com/kata0510/Lily58/blob/master/case/Lily58_case.ai

The case file in the directory of Lily58 Pro is used to make a case with FR-4

IgorLGMS, 2020-01-27:
Oh ok, thank you!

Closed 2020-07-02.

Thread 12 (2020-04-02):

Using "only one" Lily58 as a Macropad

Ferryistaken, 2020-04-02:
I would like to know if I will be able to use only "one" lily58 pcb and pro micro as a macropad/numpad using qmk, to then in the future order also the second pcb and microcontroller to make it a full keyboard. Will I be able to do this or do I need both microcontrollers and pcbs to use the lily58?

BenRoe, 2020-04-02:
You can use one half without a problem.

Ferryistaken, 2020-04-03:
One more question, What is the difference between the normal and the pro?

kata0510, 2020-07-02:
The difference between Pro and Normal (Lite) is hot swap support

Closed 2020-09-10.

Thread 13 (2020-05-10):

PCB outline is not closed

B-Raffai, 2020-05-10:
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
The outline of the PCB is open preventing step file export and breaking the 3D viewer.

If you manually adjust the outline to make the 3D viewer work, the step export will still break with the following messages.

```
Executing ‘"/usr/bin/kicad2step" --drill-origin -f -o "/home/me/source/Lily58/pcb/Lily58.step" "/home/me/source/Lily58/pcb/Lily58.kicad_pcb"’
Warning: 09:10:10: /build/kicad/src/kicad-5.1.5/utils/kicad2step/pcb/oce_utils.cpp: AddComponent: 588
Warning: * no model defined for component 'J2'
Warning: 09:10:10: /build/kicad/src/kicad-5.1.5/utils/kicad2step/pcb/oce_utils.cpp: AddComponent: 588
Warning: * no model defined for component 'R1'
Warning: 09:10:10: /build/kicad/src/kicad-5.1.5/utils/kicad2step/pcb/oce_utils.cpp: AddComponent: 588
Warning: * no model defined for component 'R1'
Warning: 09:10:10: /build/kicad/src/kicad-5.1.5/utils/kicad2step/pcb/oce_utils.cpp: AddComponent: 588
Warning: * no model defined for component 'R2'
Warning: 09:10:10: /build/kicad/src/kicad-5.1.5/utils/kicad2step/pcb/oce_utils.cpp: AddComponent: 588
Warning: * no model defined for component 'R2'
Warning: 09:10:10: /build/kicad/src/kicad-5.1.5/utils/kicad2step/pcb/oce_utils.cpp: AddComponent: 588
Warning: * no model defined for component 'P2'
Warning: 09:10:10: /build/kicad/src/kicad-5.1.5/utils/kicad2step/pcb/oce_utils.cpp: AddComponent: 588
Warning: * no model defined for component 'P2'
Warning: 09:10:10: /build/kicad/src/kicad-5.1.5/utils/kicad2step/pcb/oce_utils.cpp: AddComponent: 588
Warning: * no model defined for component 'P1'
Warning: 09:10:10: /build/kicad/src/kicad-5.1.5/utils/kicad2step/pcb/oce_utils.cpp: AddComponent: 588
Warning: * no model defined for component 'P1'
Warning: 09:10:10: /build/kicad/src/kicad-5.1.5/utils/kicad2step/pcb/oce_utils.cpp: AddComponent: 588
Warning: * no model defined for component 'W1'
Warning: 09:10:10: /build/kicad/src/kicad-5.1.5/utils/kicad2step/pcb/oce_utils.cpp: AddComponent: 588
Warning: * no model defined for component 'JP1'
Warning: 09:10:10: /build/kicad/src/kicad-5.1.5/utils/kicad2step/pcb/oce_utils.cpp: AddComponent: 588
Warning: * no model defined for component 'JP2'
Warning: 09:10:10: /build/kicad/src/kicad-5.1.5/utils/kicad2step/pcb/oce_utils.cpp: AddComponent: 588
Warning: * no model defined for component 'JP3'
Warning: 09:10:10: /build/kicad/src/kicad-5.1.5/utils/kicad2step/pcb/oce_utils.cpp: AddComponent: 588
Warning: * no model defined for component 'JP4'
Warning: 09:10:10: /build/kicad/src/kicad-5.1.5/utils/kicad2step/pcb/oce_utils.cpp: AddComponent: 588
Warning: * no model defined for component 'JP5'
Warning: 09:10:10: /build/kicad/src/kicad-5.1.5/utils/kicad2step/pcb/oce_utils.cpp: AddComponent: 588
Warning: * no model defined for component 'JP6'
Warning: 09:10:10: /build/kicad/src/kicad-5.1.5/utils/kicad2step/pcb/oce_utils.cpp: AddComponent: 588
Warning: * no model defined for component 'JP7'
Warning: 09:10:10: /build/kicad/src/kicad-5.1.5/utils/kicad2step/pcb/oce_utils.cpp: AddComponent: 588
Warning: * no model defined for component 'JP8'
Warning: 09:10:10: /build/kicad/src/kicad-5.1.5/utils/kicad2step/pcb/oce_utils.cpp: CreatePCB: 754
Warning: * could not close outline (dropping outline data with 25 segments)
Warning: + line start: 6.99333,-82.9895 end: 5.29176,-79.3181
Warning: + line start: 5.29176,-79.3181 end: 3.86311,-75.5307
Warning: + line start: 3.86311,-75.5307 end: 2.688,-71.6491
Warning: + line start: 2.688,-71.6491 end: 1.74708,-67.6952
Warning: + line start: 1.74708,-67.6952 end: 1.02097,-63.6908
Warning: + line start: 1.02097,-63.6908 end: 0.490297,-59.6577
Warning: + line start: 0.490297,-59.6577 end: 0.13569,-55.6176
Warning: + line start: 0.13569,-55.6176 end: -0.062223,-51.5923
Warning: + line start: -0.062472,-51.5922 end: -0.062472,-45.2853
Warning: + line start: -0.062472,-45.2853 end: -0.062472,-38.9784
Warning: + line start: -0.062472,-38.9784 end: -0.062472,-32.6714
Warning: + line start: -0.062472,-32.6714 end: -0.062472,-26.3645
Warning: + line start: -0.062472,-26.3645 end: -0.062472,-20.0576
Warning: + line start: -0.062472,-20.0576 end: -0.062472,-13.7506
Warning: + line start: -0.062472,-13.7506 end: -0.062472,-7.44369
Warning: + line start: -0.062472,-7.44369 end: -0.062472,-1.13676
Warning: + line start: -0.06179,-1.13676 end: -0.040477,-0.925015
Warning: + line start: -0.040477,-0.925015 end: 0.020657,-0.727855
Warning: + line start: 0.020657,-0.727855 end: 0.117409,-0.549489
Warning: + line start: 0.117409,-0.549489 end: 0.24557,-0.394123
Warning: + line start: 0.24557,-0.394123 end: 0.400937,-0.265961
Warning: + line start: 0.400937,-0.265961 end: 0.579303,-0.16921
Warning: + line start: 0.579303,-0.16921 end: 0.776462,-0.108075
Warning: + line start: 0.776462,-0.108075 end: 0.98821,-0.086762
Warning: + line start: 0.98821,-0.086762 end: 11.396,-0.086762
Warning: 09:10:10: /build/kicad/src/kicad-5.1.5/utils/kicad2step/pcb/oce_utils.cpp: CreatePCB: 754
Warning: * could not close outline (dropping outline data with 71 segments)
Warning: + line start: 21.8039,-0.086762 end: 32.2117,-0.086762
Warning: + line start: 32.2117,-0.086762 end: 42.6195,-0.086762
Warning: + line start: 42.6195,-0.086762 end: 53.0274,-0.086762
Warning: + line start: 53.0274,-0.086762 end: 63.4352,-0.086762
Warning: + line start: 63.4352,-0.086762 end: 73.843,-0.086762
Warning: + line start: 73.843,-0.086762 end: 84.2509,-0.086762
Warning: + line start: 84.2509,-0.086762 end: 95.9896,-0.215654
Warning: + line start: 95.9896,-0.215654 end: 106.92,-0.585374
Warning: + line start: 106.92,-0.585374 end: 116.808,-1.17049
Warning: + line start: 116.808,-1.17049 end: 125.421,-1.94556
Warning: + line start: 125.421,-1.94556 end: 132.526,-2.88516
Warning: + line start: 132.526,-2.88516 end: 137.889,-3.96385
Warning: + line start: 137.889,-3.96385 end: 141.278,-5.15619
Warning: + line start: 141.278,-5.15619 end: 141.9,-5.7
Warning: + line start: 141.9,-5.7 end: 142.46,-6.43675
Warning: + line start: 142.46,-6.43675 end: 142.46,-15.9184
Warning: + line start: 142.46,-15.9184 end: 142.46,-25.4
Warning: + line start: 142.46,-25.4 end: 142.46,-34.8816
Warning: + line start: 142.46,-34.8816 end: 142.46,-44.3632
Warning: + line start: 142.46,-44.3632 end: 142.46,-53.8449
Warning: + line start: 142.46,-53.8449 end: 142.46,-63.3265
Warning: + line start: 142.46,-63.3265 end: 142.46,-72.8081
Warning: + line start: 142.46,-72.8081 end: 142.46,-82.2897
Warning: + line start: 142.46,-82.2897 end: 142.43,-82.5922
Warning: + line start: 142.43,-82.5922 end: 142.342,-82.8739
Warning: + line start: 142.342,-82.8739 end: 142.204,-83.1287
Warning: + line start: 142.204,-83.1287 end: 142.021,-83.3506
Warning: + line start: 142.021,-83.3506 end: 141.799,-83.5337
Warning: + line start: 141.799,-83.5337 end: 141.544,-83.672
Warning: + line start: 141.544,-83.672 end: 141.262,-83.7593
Warning: + line start: 141.262,-83.7593 end: 140.96,-83.7897
Warning: + line start: 140.96,-83.7897 end: 135.692,-83.7897
Warning: + line start: 135.692,-83.7897 end: 130.425,-83.7897
Warning: + line start: 130.425,-83.7897 end: 125.157,-83.7897
Warning: + line start: 125.157,-83.7897 end: 119.89,-83.7897
Warning: + line start: 119.89,-83.7897 end: 114.622,-83.7897
Warning: + line start: 114.622,-83.7897 end: 109.355,-83.7897
Warning: + line start: 109.355,-83.7897 end: 104.087,-83.7897
Warning: + line start: 104.087,-83.7897 end: 98.8193,-83.7897
Warning: + line start: 98.8193,-83.7897 end: 98.1135,-83.8608
Warning: + line start: 98.1135,-83.8608 end: 97.4563,-84.0646
Warning: + line start: 97.4563,-84.0646 end: 96.8618,-84.3871
Warning: + line start: 96.8618,-84.3871 end: 96.3439,-84.8143
Warning: + line start: 96.3439,-84.8143 end: 95.9167,-85.3322
Warning: + line start: 95.9167,-85.3322 end: 95.5942,-85.9267
Warning: + line start: 95.5942,-85.9267 end: 95.3904,-86.5839
Warning: + line start: 95.3904,-86.5839 end: 95.3193,-87.2897
Warning: + line start: 95.3193,-87.2897 end: 95.3193,-88.5078
Warning: + line start: 95.3193,-88.5078 end: 95.3193,-89.7258
Warning: + line start: 95.3193,-89.7258 end: 95.3193,-90.9439
Warning: + line start: 95.3193,-90.9439 end: 95.3193,-92.1619
Warning: + line start: 95.3193,-92.1619 end: 95.3193,-93.3799
Warning: + line start: 95.3193,-93.3799 end: 95.3193,-94.598
Warning: + line start: 95.3193,-94.598 end: 95.3193,-95.816
Warning: + line start: 95.3193,-95.816 end: 95.3193,-97.0117
Warning: + line start: 95.3193,-97.0117 end: 95.2889,-97.3142
Warning: + line start: 95.2889,-97.3142 end: 95.2016,-97.5958
Warning: + line start: 95.2016,-97.5958 end: 95.0633,-97.8506
Warning: + line start: 95.0633,-97.8506 end: 94.8803,-98.0726
Warning: + line start: 94.8803,-98.0726 end: 94.6583,-98.2557
Warning: + line start: 94.6583,-98.2557 end: 94.4035,-98.3939
Warning: + line start: 94.4035,-98.3939 end: 94.1218,-98.4812
Warning: + line start: 94.1218,-98.4812 end: 93.8193,-98.5117
Warning: + line start: 93.8193,-98.5117 end: 86.4498,-98.5117
Warning: + line start: 86.4498,-98.5117 end: 79.0803,-98.5117
Warning: + line start: 79.0803,-98.5117 end: 71.7108,-98.5117
Warning: + line start: 71.7108,-98.5117 end: 64.3413,-98.5117
Warning: + line start: 64.3413,-98.5117 end: 56.9717,-98.5117
Warning: + line start: 56.9717,-98.5117 end: 49.6022,-98.5117
Warning: + line start: 49.6022,-98.5117 end: 42.2327,-98.5117
Warning: + line start: 42.2327,-98.5117 end: 34.8632,-98.5117
Warning: 09:10:10: /build/kicad/src/kicad-5.1.5/utils/kicad2step/pcb/oce_utils.cpp: CreatePCB: 754
Warning: * could not close outline (dropping outline data with 1 segments)
Warning: + line start: 21.8078,-0.086762 end: 11.4,-0.086762
Warning: 0x5629013fed00 : Standard_NullObject: A null Label has no attribute.
Error: Unable to create STEP file. Check that the board has a valid outline and models.
```

jpuerto96, 2020-09-11:
Any update on this? I am also running into the same issue when attempting to export this file to STEP.

pp222, 2020-09-17:
I just fixed right now. Will be uploading pcb file in a couple of mins.

pp222, 2020-09-17:
> Any update on this? I am also running into the same issue when attempting to export this file to STEP.

@jpuerto96 check my repository... there the pcb file is the updated one. Let me know if it's ok.

jpuerto96, 2020-09-23:
@chimuelo22 Doesn't seem like it is fixed in your repository.
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
kata0510, 2020-09-23:
outline has been fixed.
Please check.

jpuerto96, 2020-09-23:
@kata0510 I just pulled from master and did the following:

- Open KiCAD
- Open file (Lily58/pcb/Lily58.kicad_pcb) in KiCAD
- File>Export>STEP
- 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

I may be doing something wrong, but it doesn't seem to export, I get the output previously described when attempting the export.

kata0510, 2020-09-23:
@jpuerto96
sorry.
We don't support exporting STEP files until the STEP file is exported.
I can't make any changes as I'm manufacturing & selling with this data.

You may be able to solve this problem by drawing a new outline.

jpuerto96, 2020-09-23:
@kata0510 Understood - thank you for the clarification.

DanBlack3232, 2023-04-03:
HI
I'm not familiar with pcb program and i just downloaded kicad latest version but when i try to open Lily58_Pro.kicad_pcb file i get this error :
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
and its not just this file , i can't open any other projects.
can any one help me?
Thanks

Closed 2020-09-23.

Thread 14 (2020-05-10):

Via annular ring too small

B-Raffai, 2020-05-10:
All of the vias are 0.3 mm hole and 0.4 mm pad. This leaves only 0.05 mm for the annular ring.
The drill holes are never aligned perfectly so they can leave the pad or cut the connection between the track and pad. [See here](https://www.protoexpress.com/pcb/learn-pcb/annular-ring-width/).

JLCPCB recommend 0.2 mm minimum annular ring (0.3 mm hole, 0.7 mm pad). There should be enough space to change all the vias to that size.

fireglow, 2020-10-18:
I've also tried uploading the unaltered gerber files to JLCPCB and got errors, see screenshot attached.
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
@Barabas5532 did you alter the gerber files and has success at JLCPCB?

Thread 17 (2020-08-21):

For the English Build Guide Could You Add Flash Both Pro Micros Individually?

StarWhiz, 2020-08-21:
Mentioned Guide: https://github.com/kata0510/Lily58/blob/master/Pro/Doc/buildguide_en.md

When I was first building this board. I flashed both sides by accident. Then only flashed changes to keymap on the left side.

I was wondering why the lily58 keymap with encoder causes the right side to fail and not register keystrokes. When I removed encoder code from keymap it would work.

After hours of troubleshooting, it turns out all I needed to do is flash encoder keymap to both pro micros individually. Now encoder and right side works as well!

Newbies may get stuck at this not knowing that whatever they flash to one side they have to flash to the other in order to ensure everything works!

kata0510, 2020-08-21:
This English build guide is based on Lily58 Pro, which is available in Japan.
There is a Lily58 Pro PCB available outside of Japan that can be used with the encoder, but I don't have the PCB so I can't support it.
Consult the distributor. sorry.

Closed 2020-08-21.

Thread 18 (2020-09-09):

Adding additional I2C devices

foureight84, 2020-09-09:
Are there available I2C pins for additional devices? If not, would it be possible to solder the I2C directly onto the Pro Micro?

kata0510, 2020-10-19:
Lily58 Pro has a PIN for i2c communication. You can solder from there to use i2c devices (untested).

Closed 2021-03-04.

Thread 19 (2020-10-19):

JLCPCB cannot produce the Pro Top file

fireglow, 2020-10-19:
I've created a gerber file, using [this guide](https://support.jlcpcb.com/article/44-how-to-export-kicad-pcb-to-gerber-files), of the Lily58 Pro top plate ([attached](https://fireglow.de/755/gerberTOP.zip)) and sent it to JLCPCB for production, but they say:
>There are too many small slots in your file , it will take too much time to get it finished during the routing process.

How can I remedy this?

Seems like I can't upload the gerber zip file to GitHub, I've uploaded it here: https://fireglow.de/755/gerberTOP.zip

fireglow, 2020-10-19:
Oh, I just saw, they want another €12.30 to make it.
Black LeadFree HASL, 10 pieces, their initial estimate was €12.27.

jpconstantineau, 2020-10-19:
A few months ago, they have started asking more for keyboard plates for this reason.  They are also more picky when inspecting the gerbers and have been rejecting more.

kata0510, 2020-10-19:
Use a different PCB manufacturer. I use elecrow, ALLPCB.

fireglow, 2020-10-20:
Okay I see, this is not a problem with the CAD files, very good.
Thank you for the recommendations, I was looking for viable alternatives for a while now, will use them when I need something printed again.

Closed 2020-10-20.

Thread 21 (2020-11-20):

bad pcb tracing

heartpolik, 2020-11-20:
have an gap at this place
http://joxi.ru/823vQjec8aBzNm
http://joxi.net/zAN6l5ZTj8qw8A

kata0510, 2020-11-30:
Open in Kicad and there is no problem
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

japko, 2024-06-03:
I just want to leave a comment for people having same issue.

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

Debugging this was a nightmare. I'm not so skilled in soldering so I assumed this was my fault ;-)

I ordered PCB at jlcpcb.com

Closed 2021-03-04.

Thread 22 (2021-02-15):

[lily58 pro] underglow problems

FreddyJRC, 2021-02-15:
Hi, my underglow is on on both sides, and everting is working fine, but the right side is not receiving any of the rgb commands, so one the left side is rainbow and the right is static red.

Any idea why could this be happening?

kata0510, 2021-03-04:
Possibility that the left and right are out of sync.
Press the reset button on both to solve the problem?

fire1, 2022-11-13:
Same issue here, how can I debug the sync ?
@kata0510 reconnecting the USB should fix the sync...

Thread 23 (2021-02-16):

Feature req: comparison matrix

dimaqq, 2021-02-16:
It would be great to see what the difference between `pro` and `lite v2` is at a glance.
(as far as I can see these are the two generally available options now).

kata0510, 2021-03-04:
The difference in appearance between Pro and Lite Rev2 is the presence or absence of the i2c port.
The Pro uses a socket to mount the switch.
Lite Rev2 has the switch soldered in place

Here is a page with a brief comparison (Japanese)
[https://kata0510.github.io/Lily58-Document/start.html](https://kata0510.github.io/Lily58-Document/start.html)

dimaqq, 2021-03-04:
Maybe it's worth it to add this top-level readme :)

mmai, 2021-04-26:
What do the triangles and circles mean on the page?

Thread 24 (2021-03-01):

One part or the other, not both :(

BiotechPedro, 2021-03-01:
Hi Lily58 community!

I recently bought a Lily58 Pro PCB and have soldered it with MX hotswap switches. However, yesterday I tried to flash the Elite-C in Linux and had problems. I tried with "make lily58:default:dfu", the added options split-left and split-right and modifiying some lines in config.h and rules.mk files. However, the most I got was one of the parts perfectly working (left or right, depending which I define as master), but non the other (0 functionality) when conecting them with TRS or TRRS cables.

I have read about the spring pin header and so, but I think the Elite-C is not related to that, but the Pro Micro.

Any help is more than welcome!! Thanks :smiley:

BiotechPedro, 2021-03-08:
It was just a problem of not connecting well the controllers and the PCB so I close the issue

Closed 2021-03-08.

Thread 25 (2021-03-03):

Any plans for sk6812 mini-e?

fi0, 2021-03-03:
It seems to be easier to solder :)

kata0510, 2021-03-04:
There are no plans to implement YS-SK6812MINI-E on Lily58 at this time.
Sorry.

fi0, 2021-03-09:
For other people who land on this issue, there’s a glow fork and Lotus58 with mini-e support.

Closed 2021-03-04.

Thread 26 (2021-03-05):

Feature request: rotary encoder

azzamsa, 2021-03-05:
Some distributor adds rotary encoder to Lily. Unfortunately, they kept the PCB Data secrets.

I am new to this mechanical keyboard world. If only this repo has additional PCB design with a rotary encoder, or at least a fork. I will feel happy. If those companies went out of business. We can just order our own somewhere else.

I feel I just want to stick with Lily58 for a long period. Replace with another Lily if broken.

azzamsa, 2021-03-07:
Found some:

- [Lily58L](https://github.com/BenRoe/Lily58L-Build-Guide)
- [Lily58 × qtkb Glow + Rotary Encoders](https://github.com/orvisevans/Lily58-Glow-Enc)

azzamsa, 2021-03-08:
Turns out:

- [Lily58L](https://github.com/BenRoe/Lily58L-Build-Guide): Currently, the PCB design is not open source.
- [Lily58 × qtkb Glow + Rotary Encoders](https://github.com/orvisevans/Lily58-Glow-Enc): Not based on the Pro version. So it doesn't support hotswap.

azzamsa, 2021-03-09:
If you want `Lily58 original layout` + `Rotary encoder` +  `Hot-swap sockets` + `RGB` + `Open source PCB design`. I would like to recommend [Lotus58](https://github.com/TweetyDaBird/Lotus58)

Closed 2021-03-07.

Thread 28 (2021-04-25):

Kicad exported layers

fabioluciano, 2021-04-25:
Wich layers i need to export to generate a gerber file for jlcpcb?

kata0510, 2021-05-11:
Please check the JLCPCB support page.
https://support.jlcpcb.com/article/44-how-to-export-kicad-pcb-to-gerber-files

Closed 2021-05-11.

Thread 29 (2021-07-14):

Pre built

Mremmalex, 2021-07-14:
Hello,

Please can I get a link to a pre built keyboard. I don't have the resources to build one myself

MihaelN, 2021-12-16:
This is an open-source DIY repository with information on the PCB build and wiring instructions. You can find pre-assembled keyboards on the internet but do note that all of these keyboards have been assembled manually by enthusiasts.

This is not a consumer product in the sense that you can go to the store and buy it, rather look at this repository as knowledge shared on how to build this particular keyboard yourself.

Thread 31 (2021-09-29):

Lily58 Pro footprint issues

Maarrk, 2021-09-29:
When ordering manufacturing of the Pro PCBs, I ran into some issues:

- the MX hotswap socket holes have a 0.1mm hole inside them which shouldn't be there (see screenshot)
- all footprints reference `Lily58-footprint` library instead of `Lily58_Pro-footprint`
- the switch footprints reference `CherryMX_KailhLowProfile_Hotswap_Edge`, I guess they should be `MX_Choc_Hotswap` from the Pro library

The issue with the extra holes is most severe, because having holes smaller than 0.3mm in the drill file raises cost of PCB manufacturing. Even though they don't actually make sense, since they are inside bigger holes.

I don't know how the footprint libraries got so mixed up. If you don't have it sorted on your machine waiting to be commited, I'd be happy to submit a PR.

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

Maarrk, 2022-06-13:
@sungo I'm sorry, but I don't have these anymore. I'd need to start from scratch, and now I'm already on KiCad 6...

Should've just done the PR right away 😢

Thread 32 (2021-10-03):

how to enable underglow?

koraysels, 2021-10-03:
hi, i soldered some ws2812 led strips to the pins but how do I make them glow ?

MihaelN, 2021-10-10:
I had the same issue not long ago, I had to update the code to ensure all LED properties have been defined and that `left` and `right` half communicate with each other. Take a look inside [my repository](https://github.com/MihaelN/lily58pro/tree/master/firmware) for more information.

Make sure you have defined LED in the `config.h` like [this](https://github.com/MihaelN/lily58pro/blob/master/firmware/config.h).

Also take a look inside `keymap.c`, I have small snippet running different settings [here](https://github.com/MihaelN/lily58pro/blob/master/firmware/keymap.c).

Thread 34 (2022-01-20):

Updated PCB with controller integrated, hot swap and RGB per key

kevinduffey, 2022-01-20:
Been a big fan of Keeb.io Iris keyboard. Only things I desired for it were per key RGB, and I wish there was a single thumb key and single index key.. which the Lily58 design seems to have.

But.. Iris as of rev4 integrated the controller into the PCB so no more ugly controller chip sticking out and easy to damage. The new Rev6 (just released) now adds hot swap and per key RGB integrated in to the PCB. Literally no longer need to do any soldering.. which for some may be an issue.. but for many of us we just want a great keyboard with the ability to choose switches and caps.

I would like to know if there is any chance an updated Lily58 PCB can be created that does what Iris Rev 6 did.. integrate the controllers on each half, the per key RGB and the MX hot swap sockets.

With that, I think I personally would have my absolute favorite keyboard. Love my Iris.. but miss the Model 01 tab/enter keys for index fingers.. which Lily58 provides. Please make it happen. I'd pay $80 for that PCB which is what the Iris Rev6 with everything in it sells for.

BenRoe, 2022-01-22:
There is already Lily58 version available what you want, except the onboard controller. It’s called Lily58L

kevinduffey, 2022-09-11:
Yup.. I discovered this. I was hoping given that Boardsource.xyz built the Lulu from the PCB (lily58L I believe).. and how nice that came out.. that there would be a ready to use PCB with everything soldered on.. so that you just buy the pcb, case, switches, and assemble. The IRIS Rev 6 for example is $70 for the fully integrated PCB with per key RGB, hot swap switches and back light RGB LEDs and the controller, USBC between the halves, etc. I was hoping there was a chance this could be done for the Lily58 as well.

kata0510, 2023-01-08:
Lily58 Pro Rev2 is under development. Backlight LED and Type-C are supported (planned).

Serhi0, 2023-01-22:
> Lily58 Pro Rev2 está en desarrollo. Se encontró retroiluminación LED y tipo C (planificado).

when do you think you could release rev 2?

winterdouglas, 2023-12-13:
Any updates about this? :)

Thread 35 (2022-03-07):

Lifted the oled jumper pads, is there a workaround?

thraizz, 2022-03-07:
Hi, this was my first soldering project and i think i destroyed one of the oled jumper pads. The right split's oled now stays dark when connecting the keyboard. Can i somehow workaround this? The pads on the other side are fine, can I just use them? Thanks for any help in advance :)

twinoner, 2022-03-07:
using the other side pads won't help you, because that's for the other side.
In any case, and with a bit of luck and patience, you can open a little bit of the burned pads and join them via a small cable or something like that.

thraizz, 2022-03-07:
Thanks for your advice @twinoner , just using the other side is maybe a good idea - I noticed that i also soldered all leds on the wrong side of the board. I think i will desolder the pro micros, reset buttons and TRRS sockets and flip the pcbs :cat:

twinoner, 2022-03-07:
go nuts, man.. but remember to also desolder the diodes.. it will work

thraizz, 2022-03-07:
They are currently on the same side as the promicros and switches, so they can stay there, right? :D

twinoner, 2022-03-07:
I figured.. then go nuts, flip the promicros and the sockets.. that way you don't have to buy another board..
wait.. what board you have? because the lily58/pro doesn't have RGB.. or is it a custom one? I'm interested..

thraizz, 2022-03-07:
Its the lily58 rev1,can be bought as a full kit here: https://42keebs.eu/shop/kits/lily58-split-ergo-50-kit-black/

twinoner, 2022-03-07:
though it was the hot swappable.. then go nuts..
unsolder the switches, diodes (if needed) and the micro, flip them and you should be good to go..

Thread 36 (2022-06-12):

Which tact switch should I use for the Lily58 Pro?

walkxcode, 2022-06-12:
I'm looking for a good tact switch for the Lily58 Pro. What is the length the switch should be? Which one did you use?

kata0510, 2022-11-10:
It uses a 3 * 4 * 4.3mm footed tact switch.
It is a general-purpose component, so a variety of items can be used.

Closed 2022-11-10.

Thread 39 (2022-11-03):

using type-c to type-c connect to pc, no power...

gshmu, 2022-11-03:
Can not connect the computer directly with the double-headed type-c, and the keyboard is no power.

kata0510, 2022-11-10:
This is not a Lily58 problem, but a ProMicro problem.
ProMicro without CC1 and CC2 pull-downs on the Type-C connector cannot use C to C cables.

gshmu, 2022-11-11:
Thank you very much @kata0510 .
I tried  

kata0510, 2022-11-15:
Is it the same ProMicro and the same cable?

Closed 2022-11-10.

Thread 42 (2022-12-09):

Using the code for pcb

PipeEmpirico, 2022-12-09:
How do I use the code to make the pcb look in kicad?
I do not know where to put that code to be able to generate the pcb and order my board for this project. Thanks a lot

kata0510, 2023-01-08:
[KiCad](https://www.kicad.org/) is required to view PCB data

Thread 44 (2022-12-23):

Q) What's the difference between Pro Rev1 and Pro Rev2?

nanpuhaha, 2022-12-23:
What's the difference between Pro Rev1 and Pro Rev2?

kata0510, 2023-01-08:
Differences between Pro Rev1 and Rev2 (planned)
- ProMicro -> RP2040
- Choc not supported
- Backlight LED
- Rotary encoder support

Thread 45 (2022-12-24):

Please upload garber files

nanpuhaha, 2022-12-24:
I am not sure that my garber file is correct..🥺

[Gerber_Lily58 Pro_PCB_Lily58_Pro.zip](https://github.com/kata0510/Lily58/files/10298127/Gerber_Lily58.Pro_PCB_Lily58_Pro.zip)

kata0510, 2023-01-08:
Correct Gerber data depends on the PCB manufacturer.
Check out Kicad's Gerber viewer and the manufacturer's preview.

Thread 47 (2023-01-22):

Query to correctly generate the gebers

Serhi0, 2023-01-22:
Hello, I have problems with gerbers. I download the project and open it in kicad 6.
I run DRC and get various errors.
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

I follow these instructions:
[https://support.jlcpcb.com/article/194-how-to-generate-gerber-and-drill-files-in-kicad-6](url)

With the gerbers generated, I open them with kicad's gerber viewer. I get this:
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

So that several layers are incomplete. What am I doing wrong?

Kristoffer-Martinsen, 2024-05-11:
I also get the same errors. One of the errors that I get mention something about the version of kiCad so I'm guessing that something has changed between versions. I don't know if there's anyone who know a fix?

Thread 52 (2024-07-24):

Pro V2 & Lite Rev 3 changes

NourNuxeo, 2024-07-24:
Hello, a new revision of the keyboard has been uploaded a few hours ago but I couldn't find release notes.
I didn't see choc sockets in the PCBs so my biggest interrogation is It seems it's only for MX sockets ?

Thank you for your time!

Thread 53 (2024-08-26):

Pro_V2 Board design problem

anbogachev, 2024-08-26:
Hi!
I'm interested in your PCB project. I found a problem in it. Pin 2 of chip U10 is not connected to pin 14 of U3. The reason for this is the different label names.
If you are already aware of the problem, I apologise for the inconvenience.

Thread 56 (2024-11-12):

why pcb file for lily58 lite old version is missing!

4oo4e1, 2024-11-12:
i serch evey file in this github and even in japanies Lily58 documentation page
Lily58 Lite Build Guide its not there and i hope just make one layer version of it so i can easily print it in home im in contrry that can't order pcb
and thinks
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

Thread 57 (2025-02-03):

5V applied on non 5V-tolerant GPIO (SPLIT_HAND_PIN_L)

GilDev, 2025-02-03:
Hi,

I have just noticed that on the Lily58 Pro V2’s schematic, the voltage applied on the `SPLIT_HAND_PIN_L` label is wrong: it goes directly to a GPIO on the RP2040 and those are not 5V tolerant. The voltage there should be replaced by `+3V3`.

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

Have a nice day!

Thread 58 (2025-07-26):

Non pro Lily58 building guide missing

alerock26, 2025-07-26:
I'm trying to build the lily58 keyboard but everywhere the PCB pro is sold out so my only option is the regular one, I need a build guide for that PCB version since  I can see I cannot use hotswap sockets and other elements.
Where can I find this documentation?, all I can see here is related to the pro version of the PCB.

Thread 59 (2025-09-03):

Help Identifying PCB

snot-x, 2025-09-03:
I am sorry if this is not the appropriate method of asking a question, but I was given a set of old lily58 pcbs and I am unable to identify exactly which model they are as they are missing almost any identifying marks aside from the name lily58.
I have went ahead and ordered 1n4148 diodes assuming that those will be correct, but the thing I am wondering is what direction to solder them in, as the documentation shows an arrow that is missing from my PCBs.

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

twinoner, 2025-09-03:
I'm not sure, but this seems to be a "normal" Lily58 (non PRO version, the PRO is the one with hotswap)
Also, this apparently is a 'one-sided' board (so you have the LEFT and RIGHT ones)
hope this helps https://www.reddit.com/r/MechanicalKeyboards/comments/9qpfta/comment/e8aqn4v/
in the bottom left is the name of the designer of the board

twinoner, 2025-09-04:
@snot-x you can always just solder two diodes (one on each side) and test it that way
or, and I'm not a pro with tester, try it with a tester for continuity or something like that 🤔

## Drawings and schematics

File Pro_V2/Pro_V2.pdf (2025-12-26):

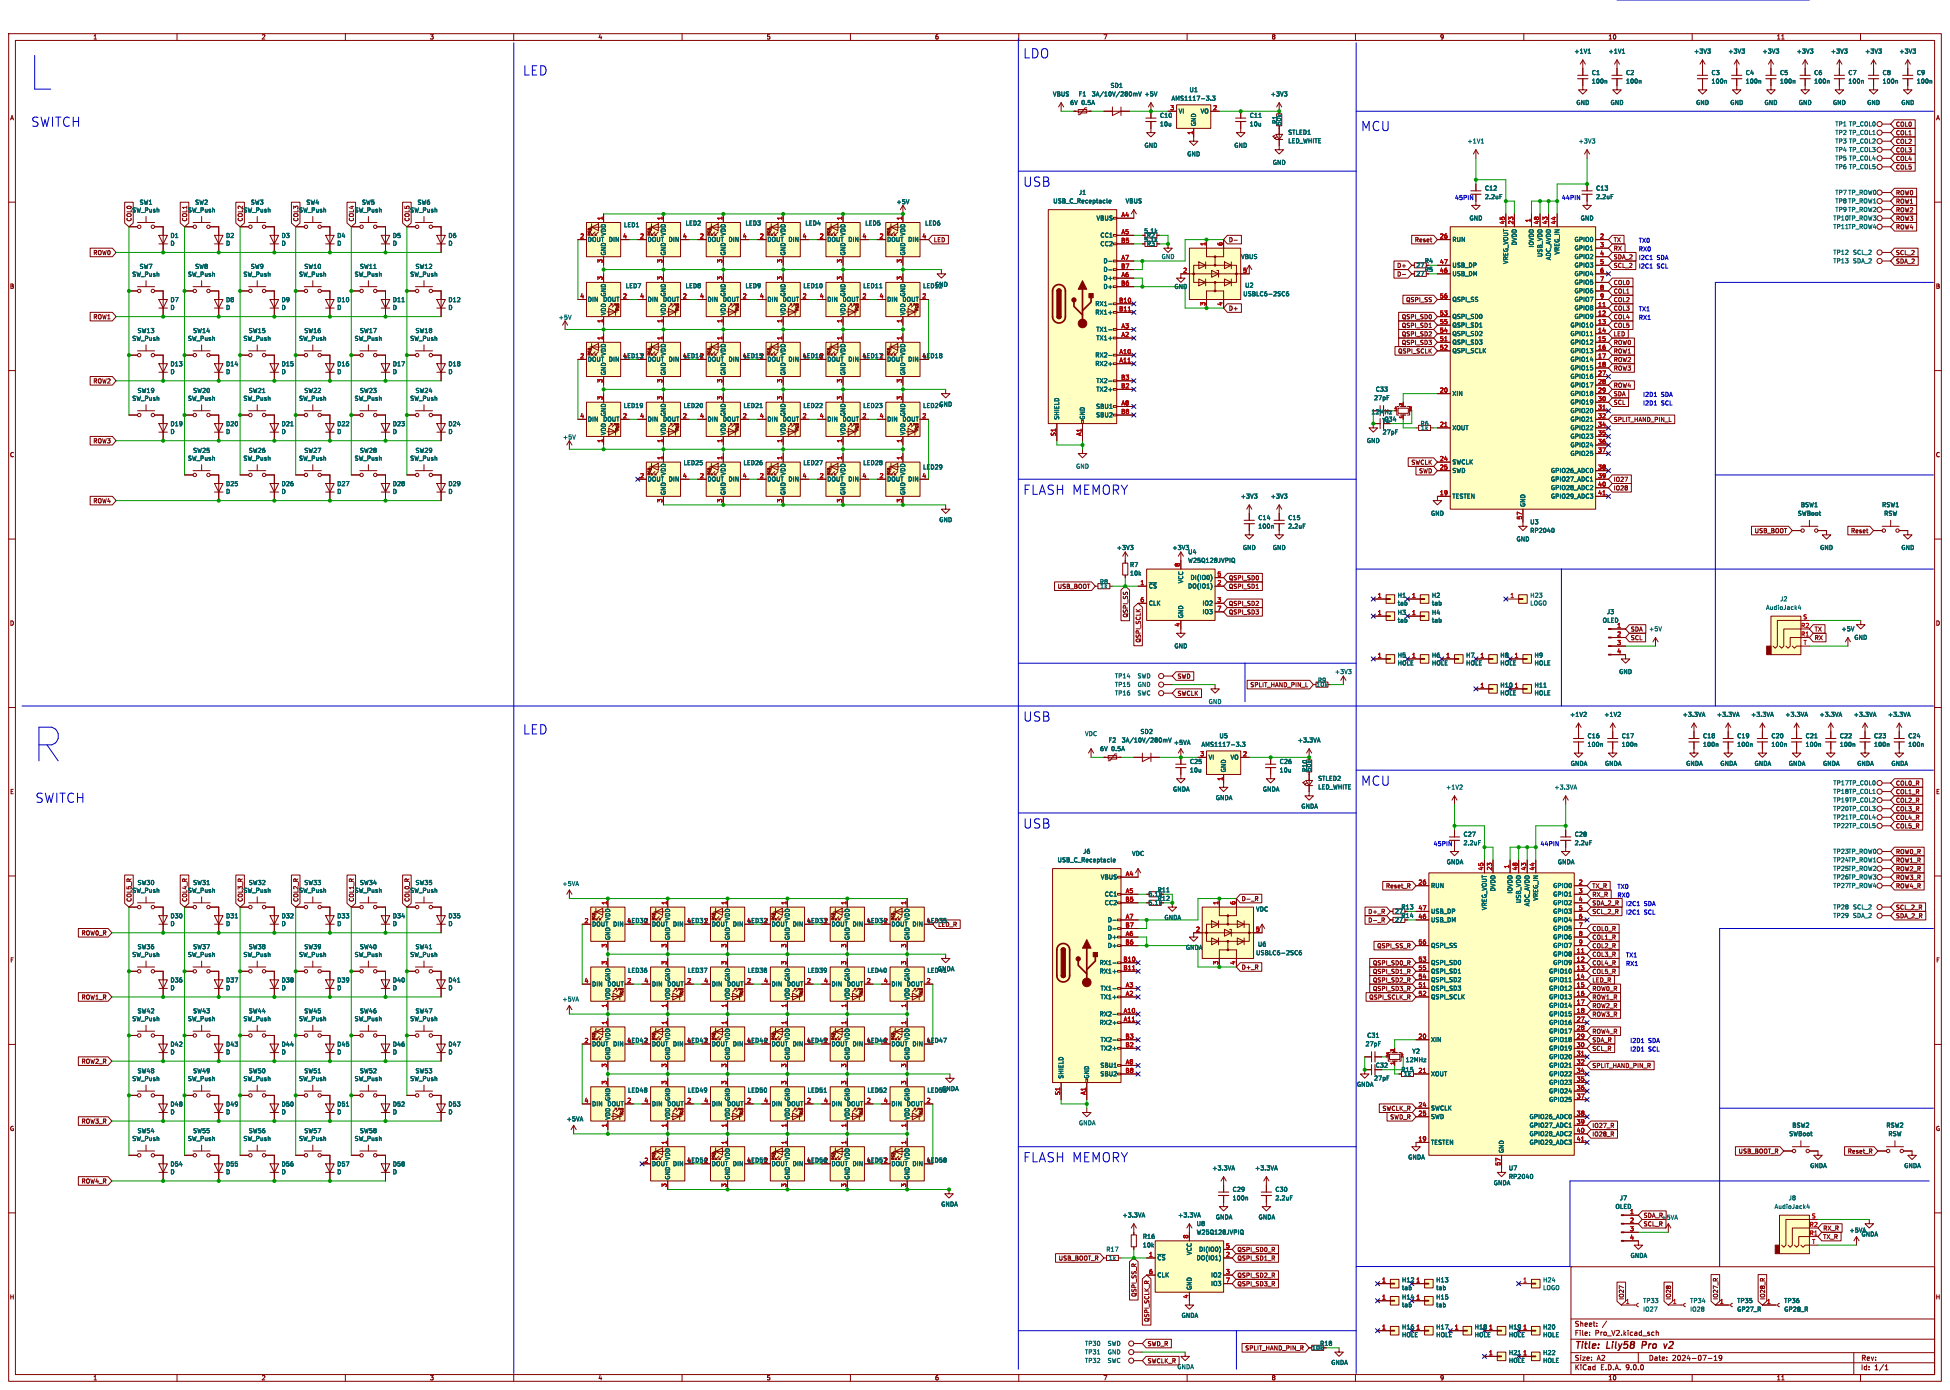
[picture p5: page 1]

1 GNDA GNDA R12 5.1k GNDAGNDA GNDA

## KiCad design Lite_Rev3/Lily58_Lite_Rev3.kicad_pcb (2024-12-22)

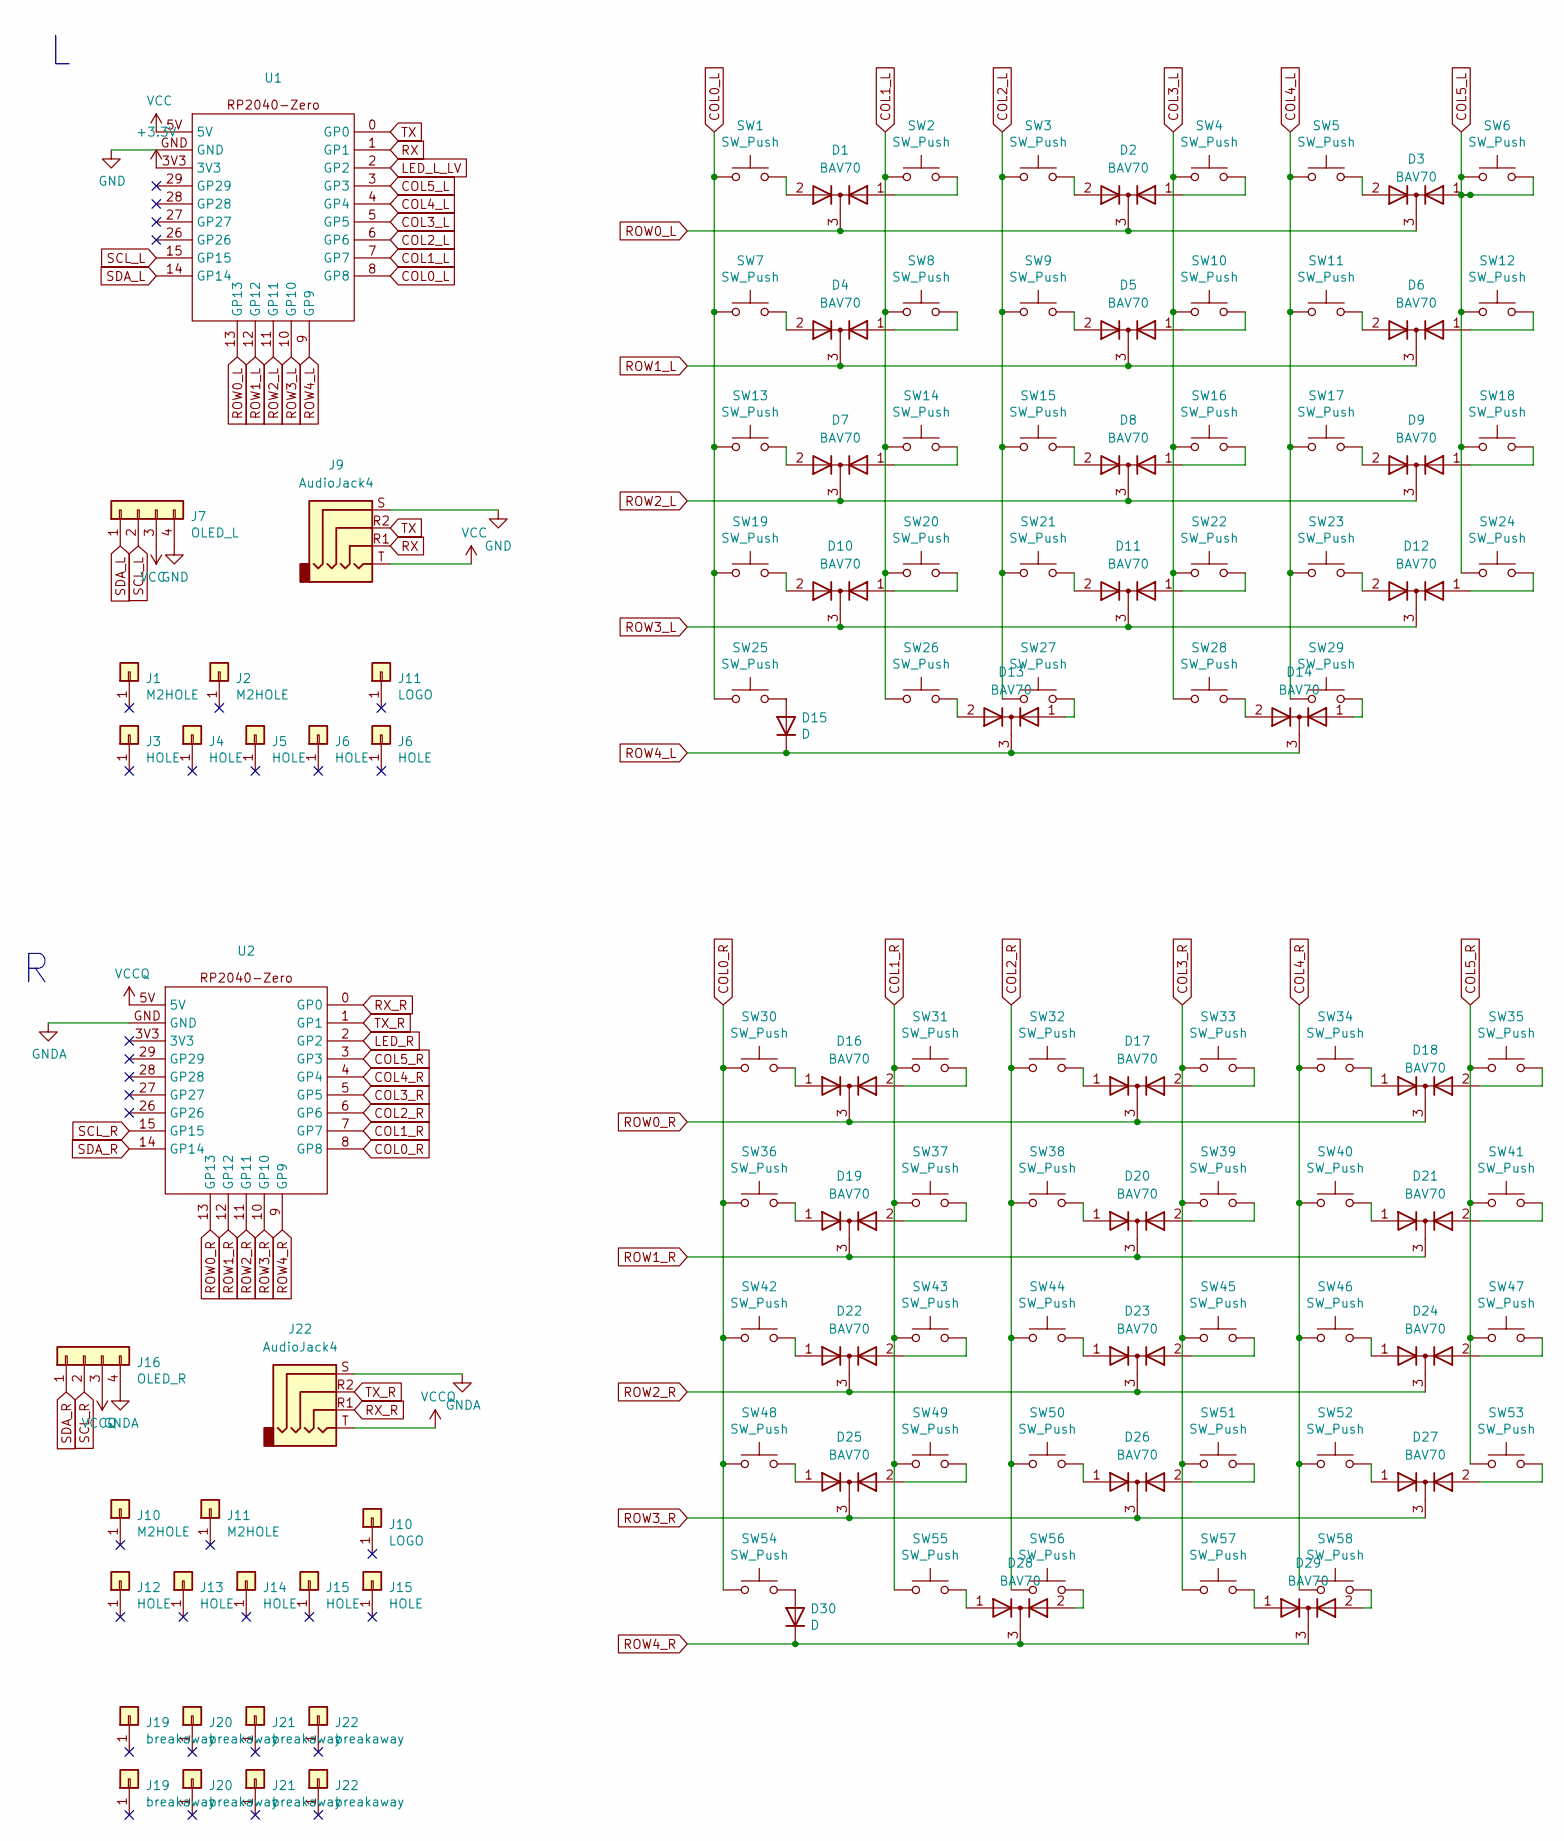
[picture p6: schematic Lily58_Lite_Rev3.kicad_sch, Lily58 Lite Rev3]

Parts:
D1, D2, D3, D4, D5, D6, D7, D8, D9, D10, D11, D12, D13, D14, D16, D17, D18, D19, D20, D21, D22, D23, D24, D25, D26, D27, D28, D29: BAV70; SOT-23
D15, D30: D; D_SOD-123
J1, J2, J11: M2HOLE; M2_HOLE_PCB
J3, J4, J5, J6, J12, J13, J14, J15: HOLE; HOLE_M2_TH
J7: OLED_L; OLED_4Pin
J9: AudioJack4; PJ-320
J10: LOGO; lily58_logo_2
J16: OLED_R; OLED_4Pin
J19, J20, J21, J22: breakaway; breakaway04
SW1, SW2, SW3, SW4, SW5, SW6, SW7, SW8, SW9, SW10, SW11, SW12, SW13, SW14, SW15, SW16, SW17, SW18, SW19, SW20, SW21, SW22, SW23, SW24, SW25, SW26, SW27, SW28, SW29, SW30, SW31, SW32, SW33, SW34, SW35, SW36, SW37, SW38, SW39, SW40, SW41, SW42, SW43, SW44, SW45, SW46, SW47, SW48, SW49, SW50, SW51, SW52, SW53, SW54, SW55, SW56, SW57, SW58: SW_Push; MX_HOLE
U1, U2: RP2040-Zero_bottom

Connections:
+3.3V: U1.3V3
COL0_L: SW1.1, SW7.1, SW13.1, SW19.1, SW25.1, U1.8 (GP8)
COL0_R: SW30.1, SW36.1, SW42.1, SW48.1, SW54.1, U2.8 (GP8)
COL1_L: SW2.1, SW8.1, SW14.1, SW20.1, SW26.1, U1.7 (GP7)
COL1_R: SW31.1, SW37.1, SW43.1, SW49.1, SW55.1, U2.7 (GP7)
COL2_L: SW3.1, SW9.1, SW15.1, SW21.1, SW27.1, U1.6 (GP6)
COL2_R: SW32.1, SW38.1, SW44.1, SW50.1, SW56.1, U2.6 (GP6)
COL3_L: SW4.1, SW10.1, SW16.1, SW22.1, SW28.1, U1.5 (GP5)
COL3_R: SW33.1, SW39.1, SW45.1, SW51.1, SW57.1, U2.5 (GP5)
COL4_L: SW5.1, SW11.1, SW17.1, SW23.1, SW29.1, U1.4 (GP4)
COL4_R: SW34.1, SW40.1, SW46.1, SW52.1, SW58.1, U2.4 (GP4)
COL5_R: SW35.1, SW41.1, SW47.1, SW53.1, U2.3 (GP3)
GND: J7.4, J9.S, U1.GND
GNDA: J16.4, J22.S, U2.GND
LED_L_LV: U1.2 (GP2)
LED_R: U2.2 (GP2)
unnamed: D1.1 (A), SW2.2
unnamed: D1.2 (A), SW1.2
unnamed: D2.1 (A), SW4.2
unnamed: D2.2 (A), SW3.2
unnamed: D3.2 (A), SW5.2
unnamed: D4.1 (A), SW8.2
unnamed: D4.2 (A), SW7.2
unnamed: D5.1 (A), SW10.2
unnamed: D5.2 (A), SW9.2
unnamed: D6.1 (A), SW12.2
unnamed: D6.2 (A), SW11.2
unnamed: D7.1 (A), SW14.2
unnamed: D7.2 (A), SW13.2
unnamed: D8.1 (A), SW16.2
unnamed: D8.2 (A), SW15.2
unnamed: D9.1 (A), SW18.2
unnamed: D9.2 (A), SW17.2
unnamed: D10.1 (A), SW20.2
unnamed: D10.2 (A), SW19.2
unnamed: D11.1 (A), SW22.2
unnamed: D11.2 (A), SW21.2
unnamed: D12.1 (A), SW24.2
unnamed: D12.2 (A), SW23.2
unnamed: D13.1 (A), SW27.2
unnamed: D13.2 (A), SW26.2
unnamed: D14.1 (A), SW29.2
unnamed: D14.2 (A), SW28.2
unnamed: D15.2 (A), SW25.2
unnamed: D16.1 (A), SW30.2
unnamed: D16.2 (A), SW31.2
unnamed: D17.1 (A), SW32.2
unnamed: D17.2 (A), SW33.2
unnamed: D18.1 (A), SW34.2
unnamed: D18.2 (A), SW35.2
unnamed: D19.1 (A), SW36.2
unnamed: D19.2 (A), SW37.2
unnamed: D20.1 (A), SW38.2
unnamed: D20.2 (A), SW39.2
unnamed: D21.1 (A), SW40.2
unnamed: D21.2 (A), SW41.2
unnamed: D22.1 (A), SW42.2
unnamed: D22.2 (A), SW43.2
unnamed: D23.1 (A), SW44.2
unnamed: D23.2 (A), SW45.2
unnamed: D24.1 (A), SW46.2
unnamed: D24.2 (A), SW47.2
unnamed: D25.1 (A), SW48.2
unnamed: D25.2 (A), SW49.2
unnamed: D26.1 (A), SW50.2
unnamed: D26.2 (A), SW51.2
unnamed: D27.1 (A), SW52.2
unnamed: D27.2 (A), SW53.2
unnamed: D28.1 (A), SW55.2
unnamed: D28.2 (A), SW56.2
unnamed: D29.1 (A), SW57.2
unnamed: D29.2 (A), SW58.2
unnamed: D30.2 (A), SW54.2
RESET_L: U1.26 (GP26)
RESET_R: U2.26 (GP26)
ROW0_L: D1.3 (K), D2.3 (K), D3.3 (K), U1.13 (GP13)
ROW0_R: D16.3 (K), D17.3 (K), D18.3 (K), U2.13 (GP13)
ROW1_L: D4.3 (K), D5.3 (K), D6.3 (K), U1.12 (GP12)
ROW1_R: D19.3 (K), D20.3 (K), D21.3 (K), U2.12 (GP12)
ROW2_L: D7.3 (K), D8.3 (K), D9.3 (K), U1.11 (GP11)
ROW2_R: D22.3 (K), D23.3 (K), D24.3 (K), U2.11 (GP11)
ROW3_L: D10.3 (K), D11.3 (K), D12.3 (K), U1.10 (GP10)
ROW3_R: D25.3 (K), D26.3 (K), D27.3 (K), U2.10 (GP10)
ROW4_L: D13.3 (K), D14.3 (K), D15.1 (K), U1.9 (GP9)
ROW4_R: D28.3 (K), D29.3 (K), D30.1 (K), U2.9 (GP9)
RX: J9.R1, U1.1 (GP1)
RX_R: J22.R1, U2.0 (GP0)
SCL_L: J7.2, U1.15 (GP15)
SCL_R: J16.2, U2.15 (GP15)
SDA_L: J7.1, U1.14 (GP14)
SDA_R: J16.1, U2.14 (GP14)
TX: J9.R2, U1.0 (GP0)
TX_R: J22.R2, U2.1 (GP1)
VCC: J7.3, J9.T, U1.5V
VCCQ: J16.3, J22.T, U2.5V

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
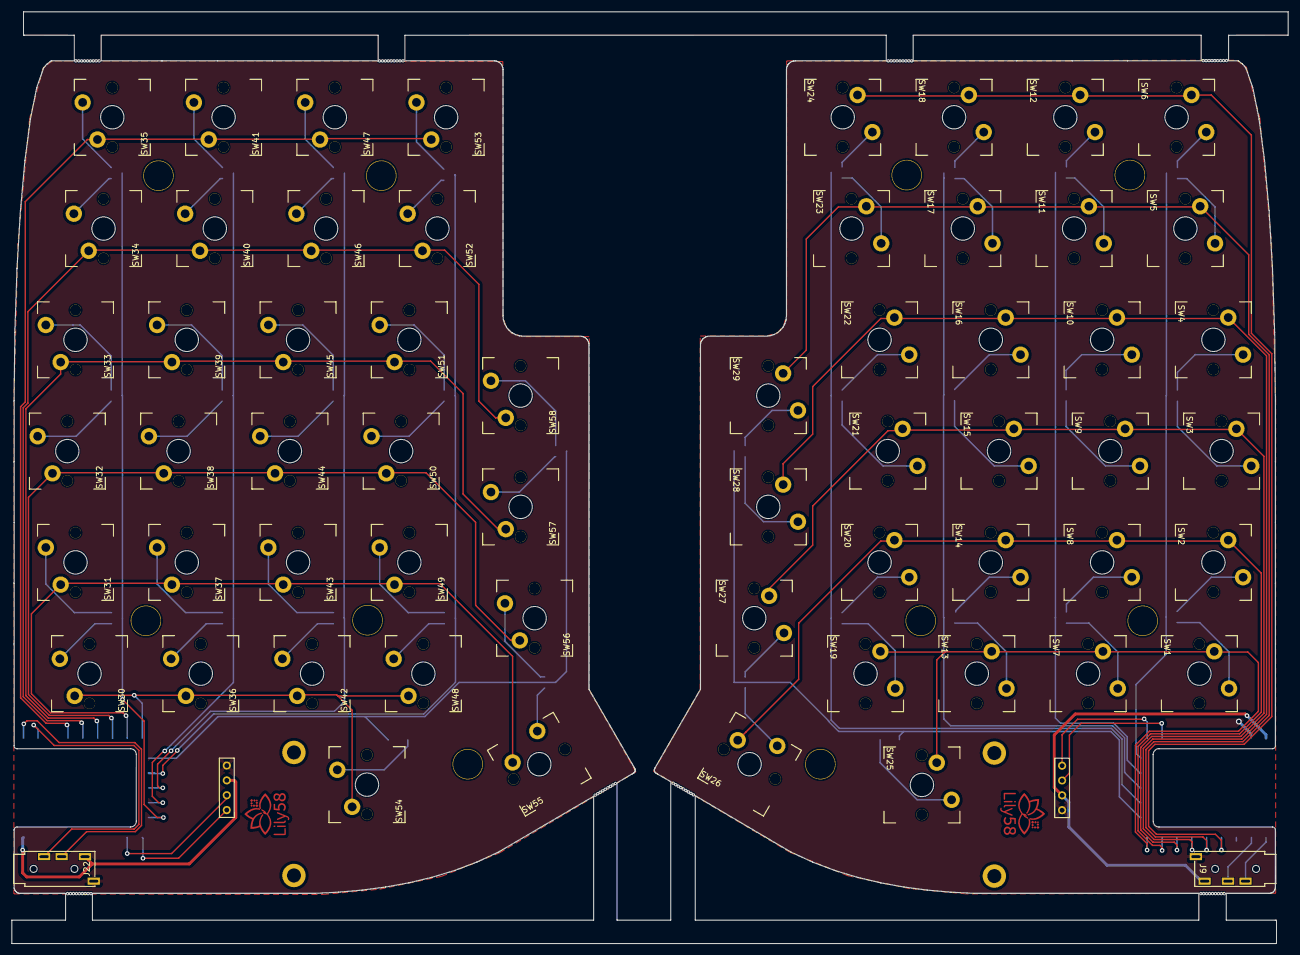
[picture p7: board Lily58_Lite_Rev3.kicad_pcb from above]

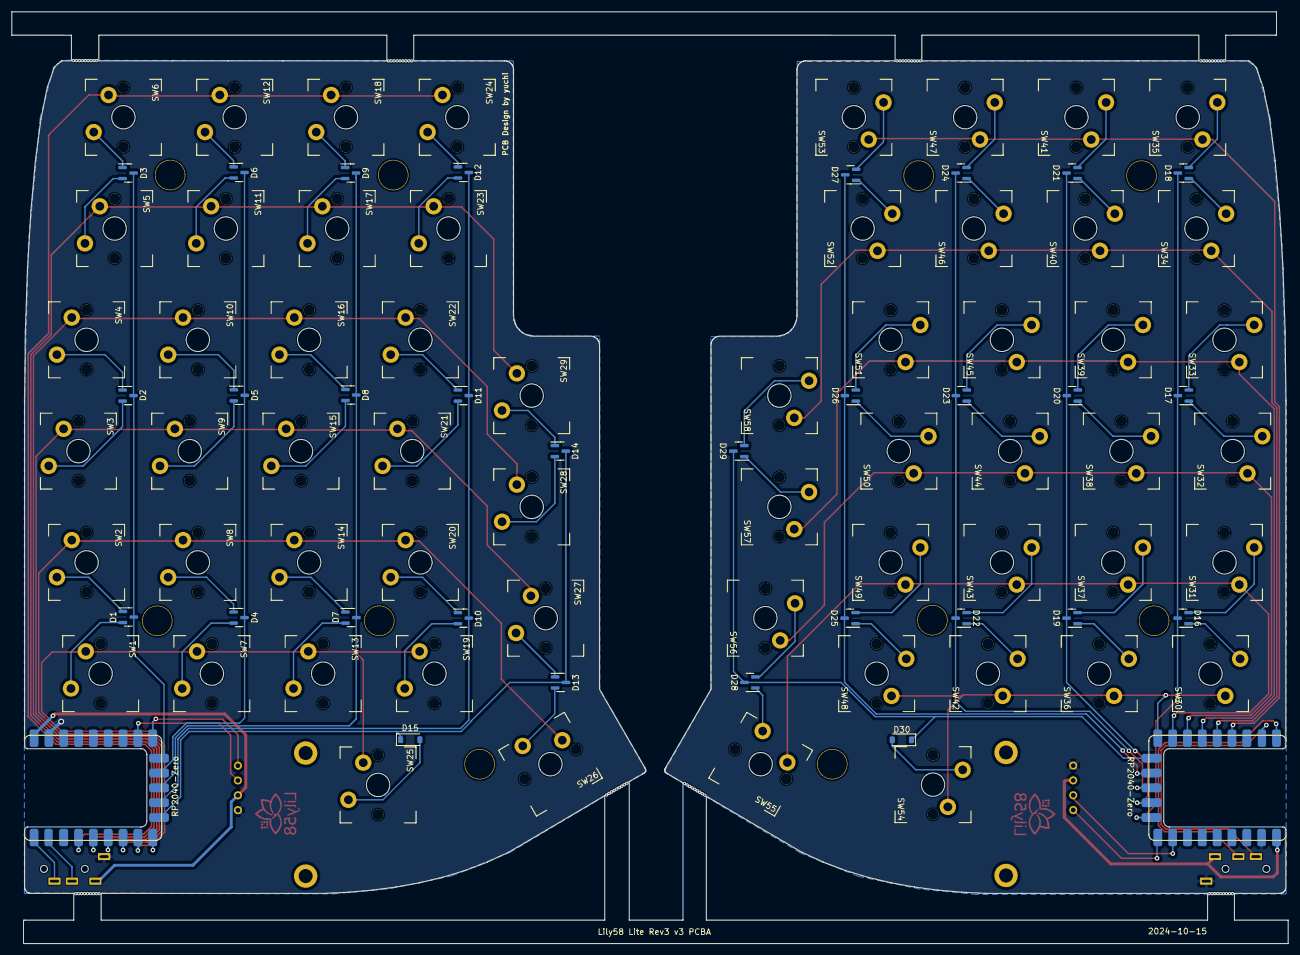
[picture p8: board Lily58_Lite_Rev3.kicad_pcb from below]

Board: 2 copper layers, 218.5 x 159.5 mm, 118 parts (34 on the bottom side), 92 nets.

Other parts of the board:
J8, J17, J18, J25, J26: breakaway; breakaway04
J23, J24: HOLE; HOLE_M2_TH_5mm
L01, L02: LOGO; lily58_logo_2

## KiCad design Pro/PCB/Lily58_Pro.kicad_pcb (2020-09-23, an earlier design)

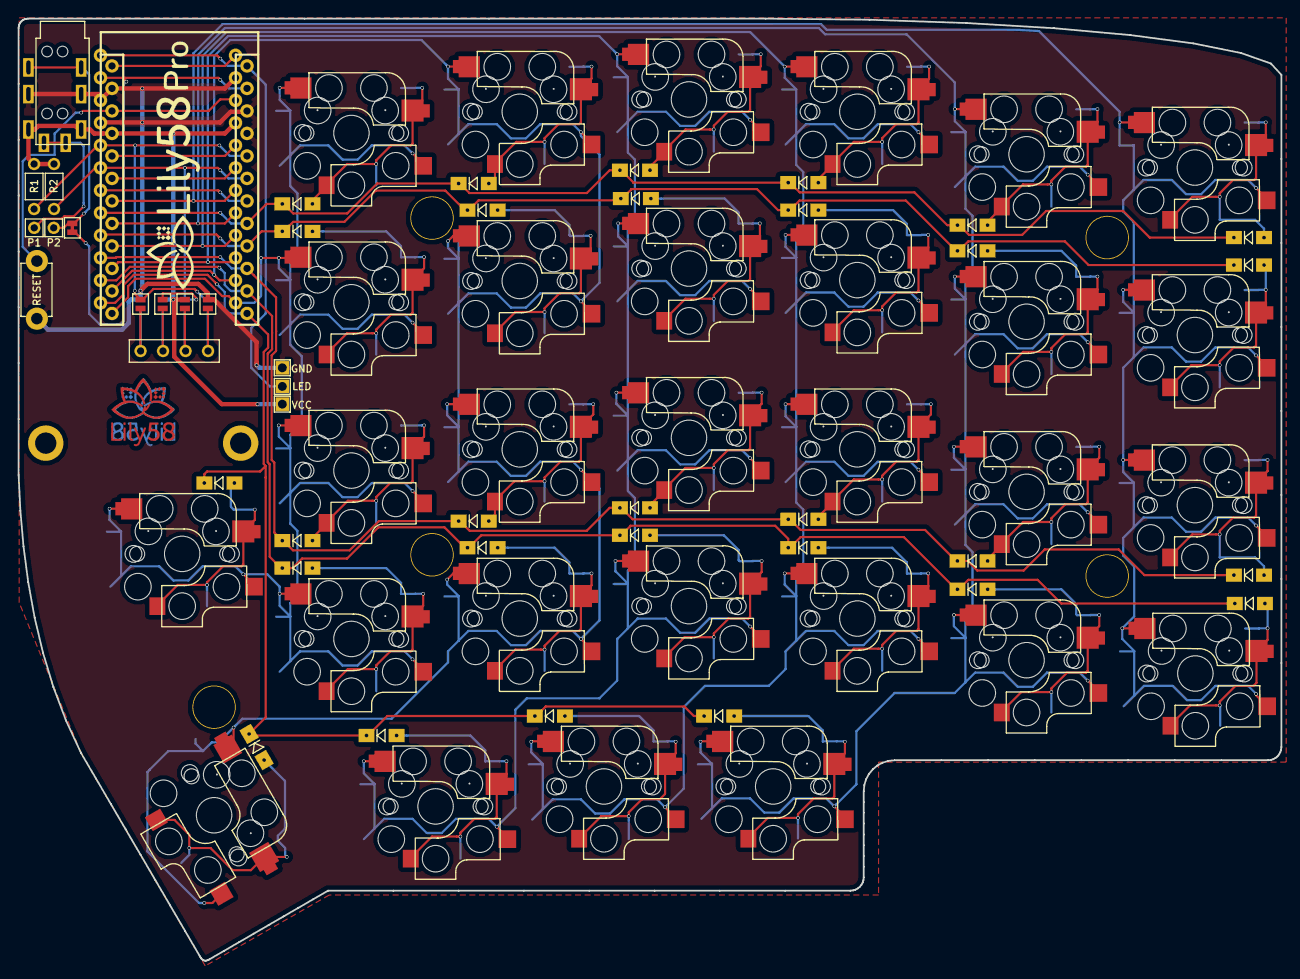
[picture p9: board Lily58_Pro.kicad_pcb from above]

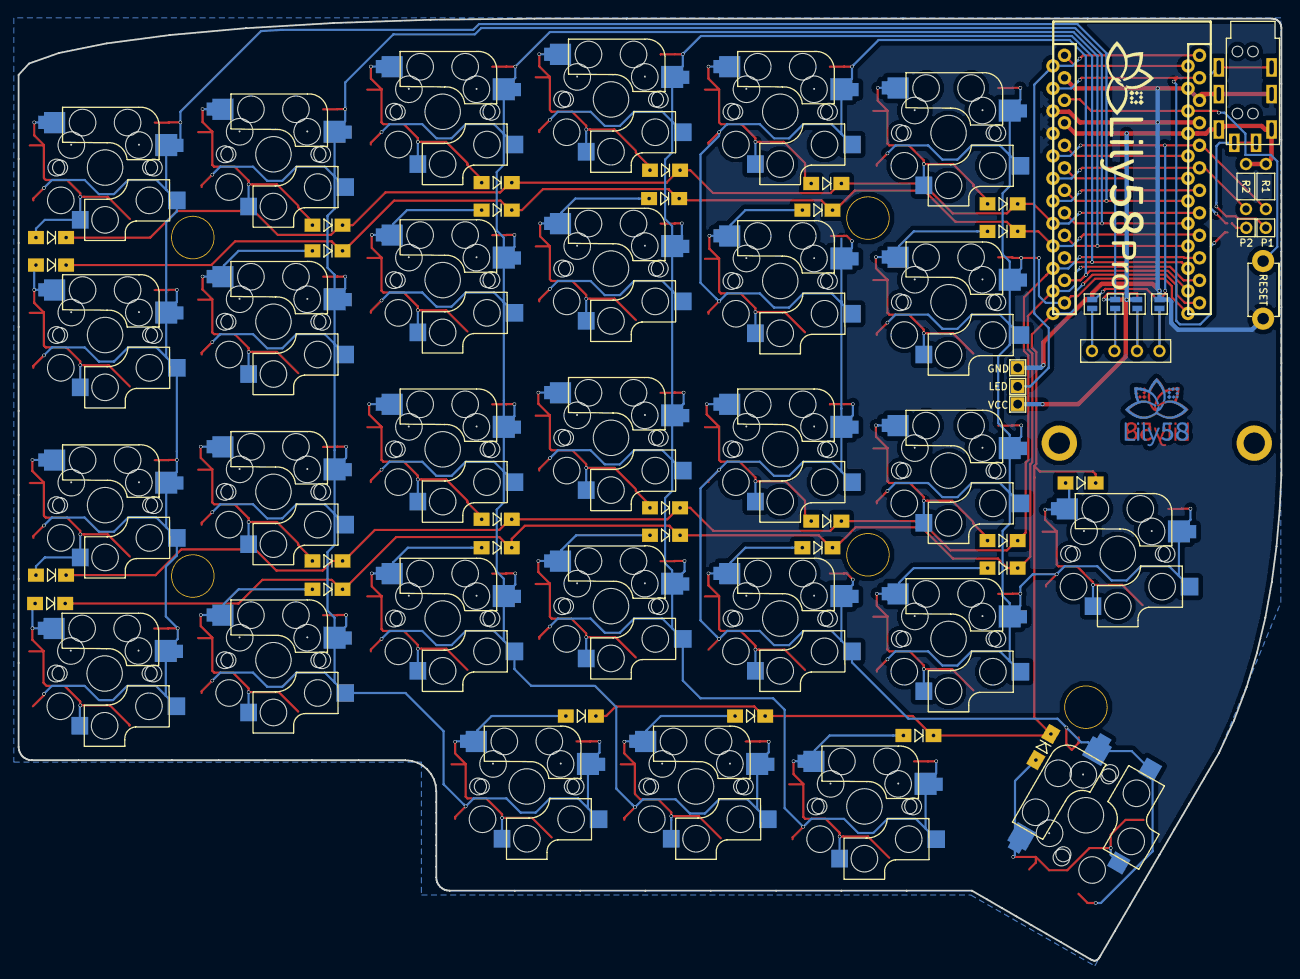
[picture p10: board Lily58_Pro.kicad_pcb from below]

Board: 2 copper layers, 142.5 x 106.3 mm, 83 parts (4 on the bottom side), 53 nets.

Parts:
D1, D2, D3, D4, D5, D6, D7, D8, D9, D10, D11, D12, D13, D14, D15, D16, D17, D18, D19, D20, D21, D22, D23, D24, D25, D26, D27, D28, D29: D; Diode_SOD123
J1: LED
J2: 4PIN; MJ-4PP-9
J3: OLED; OLED_4Pin
JP1, JP2, JP3, JP4, JP5, JP6, JP7, JP8: Jumper
P1, P2: i2c_pin; 1pin_conn
R1, R2: R; RESISTOR_mini
RSW1: SW_RST; TACT_SWITCH_TVBP06
SW1, SW2, SW3, SW4, SW5, SW6, SW7, SW8, SW9, SW10, SW11, SW12, SW13, SW14, SW15, SW16, SW17, SW18, SW19, SW20, SW21, SW22, SW23, SW24, SW25, SW26, SW27, SW28, SW29: SW_PUSH; CherryMX_KailhLowProfile_Hotswap_edge
TH1, TH2: HOLE; M2_HOLE_PCB
TH3, TH4, TH5, TH6, TH7: HOLE; HOLE_M2_TH
U1: ProMicro; ProMicro_rev2
W1: jumper; jumper_data

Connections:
DATA: U1.2, W1.1
GND: J1.3, J2.2, JP1.2, JP8.2, RSW1.1, U1.3, U1.4, U1.23
LED: J1.2, U1.1
unnamed: D1.2, SW1.2
unnamed: D2.2, SW2.2
unnamed: D3.2, SW3.2
unnamed: D4.2, SW4.2
unnamed: D5.2, SW5.2
unnamed: D6.2, SW6.2
unnamed: D7.2, SW7.2
unnamed: D8.2, SW8.2
unnamed: D9.2, SW9.2
unnamed: D10.2, SW10.2
unnamed: D11.2, SW11.2
unnamed: D12.2, SW12.2
unnamed: D13.2, SW13.2
unnamed: D14.2, SW14.2
unnamed: D15.2, SW15.2
unnamed: D16.2, SW16.2
unnamed: D17.2, SW17.2
unnamed: D18.2, SW18.2
unnamed: D19.2, SW19.2
unnamed: D20.2, SW20.2
unnamed: D21.2, SW21.2
unnamed: D22.2, SW22.2
unnamed: D23.2, SW23.2
unnamed: D24.2, SW24.2
unnamed: D25.2, SW25.2
unnamed: D26.2, SW26.2
unnamed: D27.2, SW27.2
unnamed: D28.2, SW28.2
unnamed: D29.2, SW29.2
unnamed: J2.3, P2.1, W1.2
unnamed: J2.4, P1.1
unnamed: J3.1, JP4.1, JP8.1
unnamed: J3.2, JP3.1, JP7.1
unnamed: J3.3, JP2.1, JP6.1
unnamed: J3.4, JP1.1, JP5.1
RESET: RSW1.2, U1.22
SCL: JP3.2, JP6.2, R2.2, U1.6
SDA: JP4.2, JP5.2, R1.2, U1.5
VCC: J1.1, J2.1, JP2.2, JP7.2, R1.1, R2.1, U1.21
col0: SW6.1, SW12.1, SW18.1, SW24.1, U1.18
col1: SW5.1, SW11.1, SW17.1, SW23.1, SW29.1, U1.17
col2: SW4.1, SW10.1, SW16.1, SW22.1, SW28.1, U1.16
col3: SW3.1, SW9.1, SW15.1, SW21.1, SW27.1, U1.15
col4: SW2.1, SW8.1, SW14.1, SW20.1, SW26.1, U1.14
col5: SW1.1, SW7.1, SW13.1, SW19.1, SW25.1, U1.13
row0: D1.1, D2.1, D3.1, D4.1, D5.1, D6.1, U1.8
row1: D7.1, D8.1, D9.1, D10.1, D11.1, D12.1, U1.9
row2: D13.1, D14.1, D15.1, D16.1, D17.1, D18.1, U1.10
row3: D19.1, D20.1, D21.1, D22.1, D23.1, D24.1, U1.11
row4: D25.1, D26.1, D27.1, D28.1, D29.1, U1.12

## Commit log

2018-08-21 add PCB
    [Lily58.kicad_pcb, Lily58.sch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]
2018-08-21 add case data
2018-08-29 fix case
2018-09-06 update PCB 0.1->0.2
    [Lily58.kicad_pcb, Lily58.sch]
2018-09-11 update other
    [Lily58-B.Cu.GBL, Lily58-B.Mask.GBS, Lily58-B.SilkS.GBO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]
2018-10-22 fix PCB
    [Lily58.kicad_pcb, Lily58.sch]
2019-02-05 Add Lily58 Pro PCB Data
    [Lily58_Pro.kicad_pcb, Lily58_Pro.sch, Lily58_Pro_BOTTOM.kicad_pcb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]
2019-02-23 Add Lily58 Pro PCBData
2019-02-23 Lily58 PCBData update
    [Lily58.kicad_pcb, Lily58.sch]
2019-06-05 Add English translation of the build guide for the Pro kit. I don't speak Japanese, so this is a rough translation based on Google Translate and some experience building this board.
2020-09-23 fix Lily58 PCB
    [Lily58.kicad_pcb]
2020-09-23 fix Lily58 Pro PCB outline #13
    [Lily58_Pro.kicad_pcb]
2022-12-04 Add Lily58 Pro Rev2(RP2040)
    [Pro_Rev2.kicad_sch]
2023-08-15 add Lily58 Pro Rev2 PCB
    [Pro_Rev2.kicad_sch]
2024-02-03 Update Lily58 ProRev2
    [Pro_Rev2.kicad_sch]
2024-07-15 Update Lily58 Pro V2
    [Pro_Rev2.kicad_sch]
2024-07-15 rename to Lily58 Pro V2
    [Pro_V2.kicad_sch]
2024-07-24 Pro v2 update
    [Pro_V2.kicad_sch]
2024-07-24 Lily58 Pro v2 Rename
    [Pro_V2.kicad_sch]
2024-07-24 add Lily58 Lite Rev3
    [Lily58_Lite_Rev3.kicad_pcb, Lily58_Lite_Rev3.kicad_sch]
2024-07-30 [Lily58 Lite Rev3] Fix silk rotate
    [Lily58_Lite_Rev3.kicad_pcb]
2024-10-24 [Lily58 Lite Rev3] Fix SW54
    [Lily58_Lite_Rev3.kicad_pcb, Lily58_Lite_Rev3.kicad_sch, Pro_V2.kicad_sch]
2024-12-22 [Lily58 Lite Rev3] fix PCB
    [Lily58_Lite_Rev3.kicad_pcb, Lily58_Lite_Rev3.kicad_sch]
2024-12-22 add PCB Top Plate
    [Lily58_Lite_Rev3_TOP_Case.kicad_pcb, Lily58_Lite_Rev3_TOP_Case.kicad_sch]
2025-12-26 fix SPLIT_HAND_PIN_L Pin #57
    [Pro_V2.kicad_sch]
